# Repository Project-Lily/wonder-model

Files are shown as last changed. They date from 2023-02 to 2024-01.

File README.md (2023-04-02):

<div style="text-align: center">
<h1>Wonder Reader</h1>
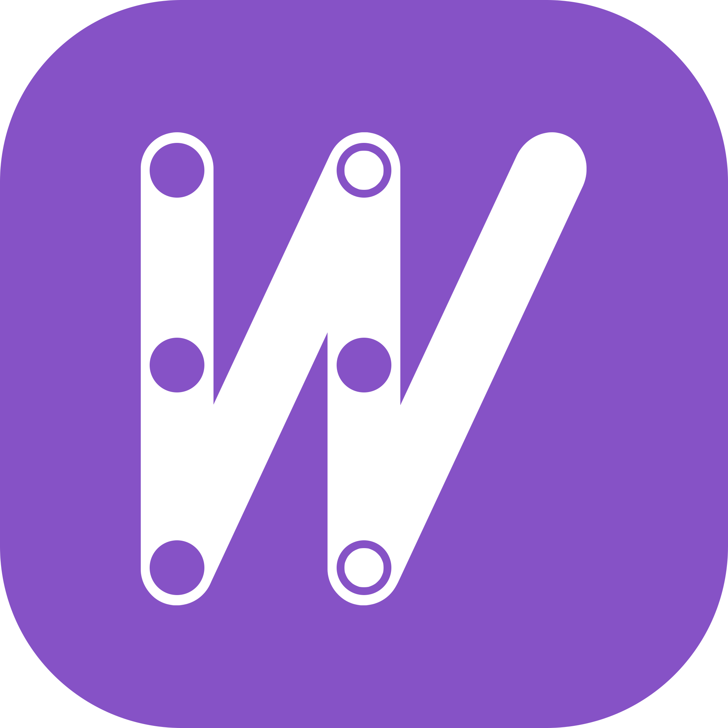
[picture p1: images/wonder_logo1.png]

<p>Repository for circuit, and 3D CAD models<p>
</div>

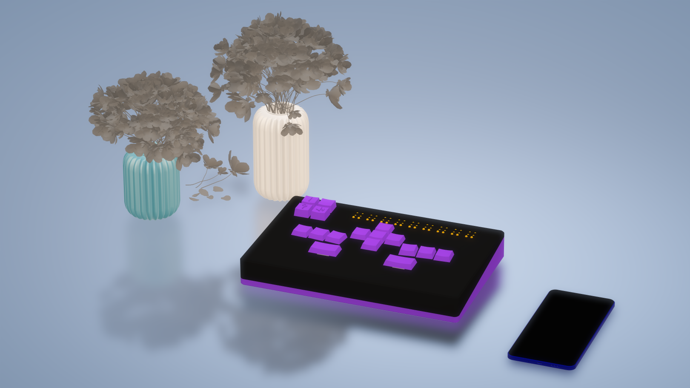
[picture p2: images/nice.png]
nice


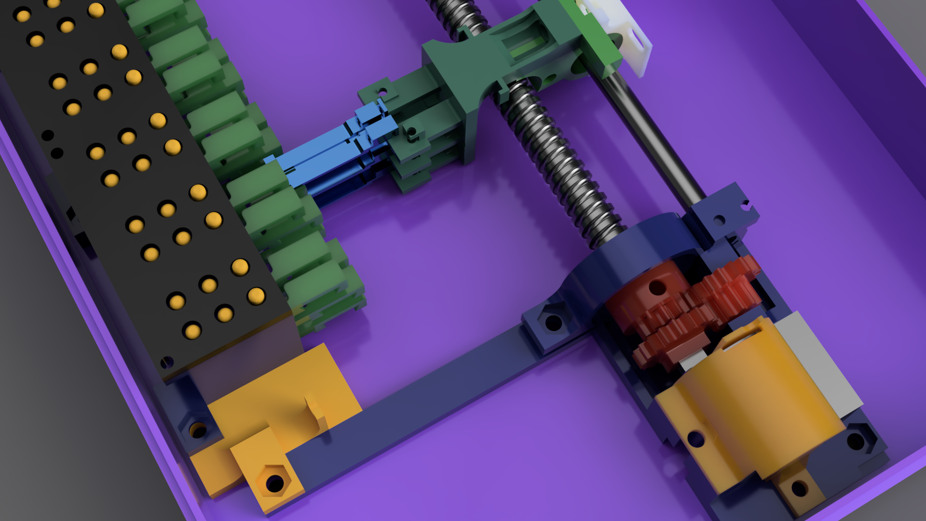
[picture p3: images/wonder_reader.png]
header


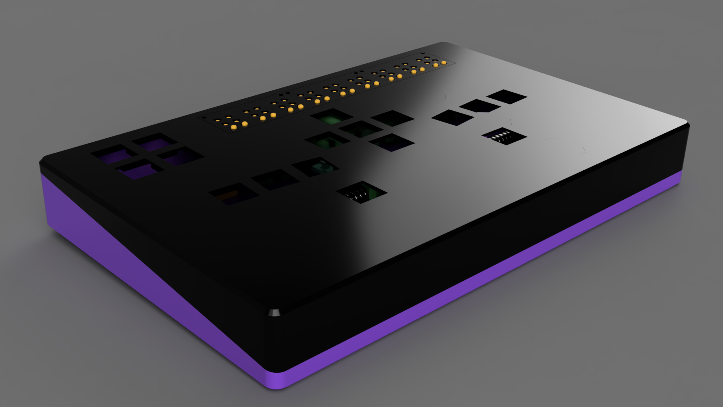
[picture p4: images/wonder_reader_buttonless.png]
buttonless


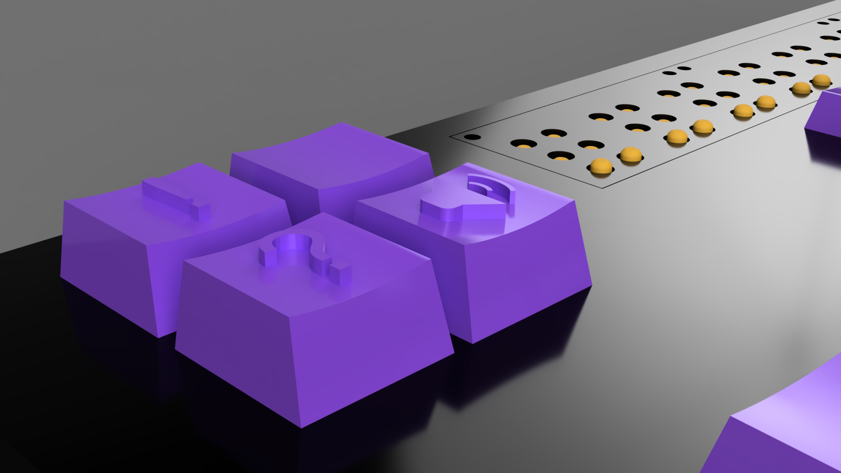
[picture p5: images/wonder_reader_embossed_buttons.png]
buttons


### Circuit
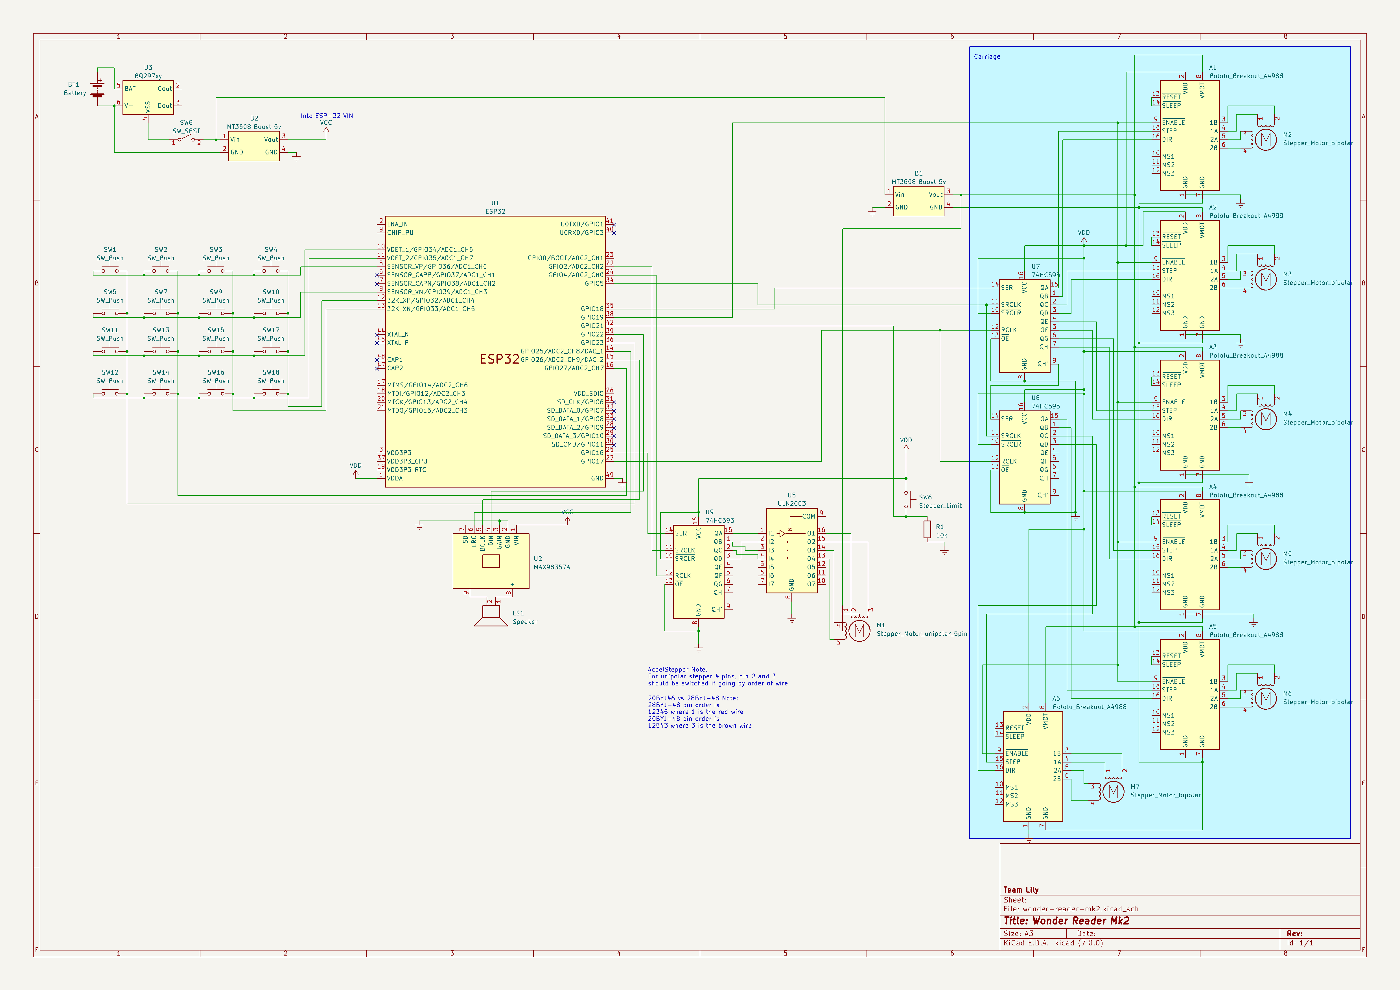
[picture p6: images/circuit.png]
circuit


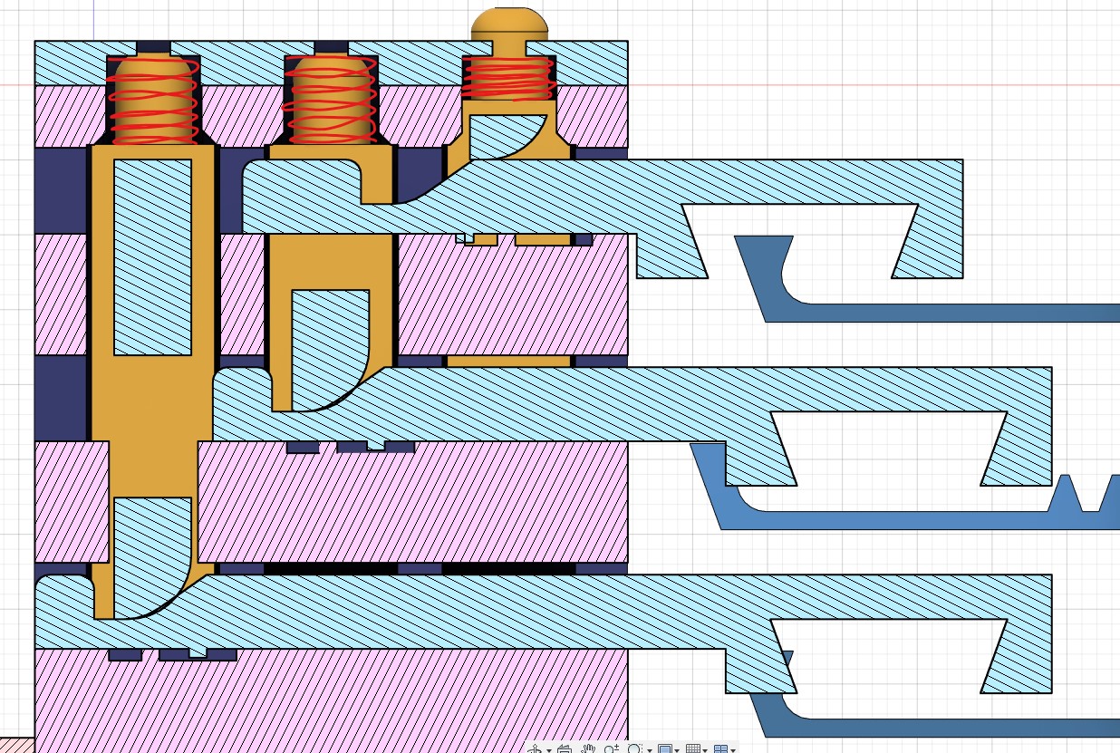
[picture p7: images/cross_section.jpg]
cross_section


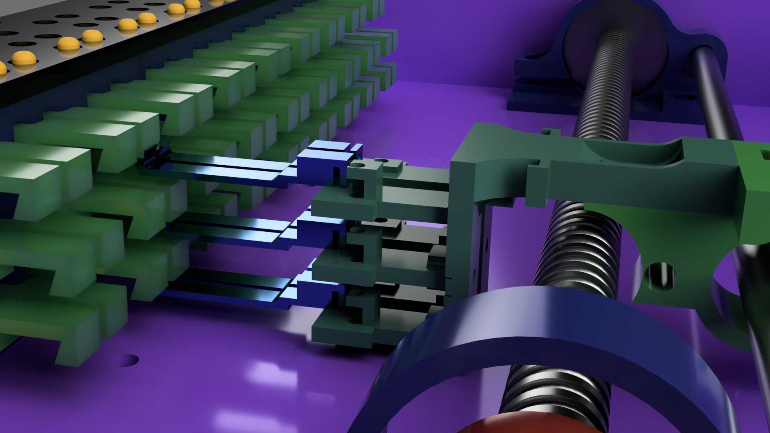
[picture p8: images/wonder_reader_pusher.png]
pusher


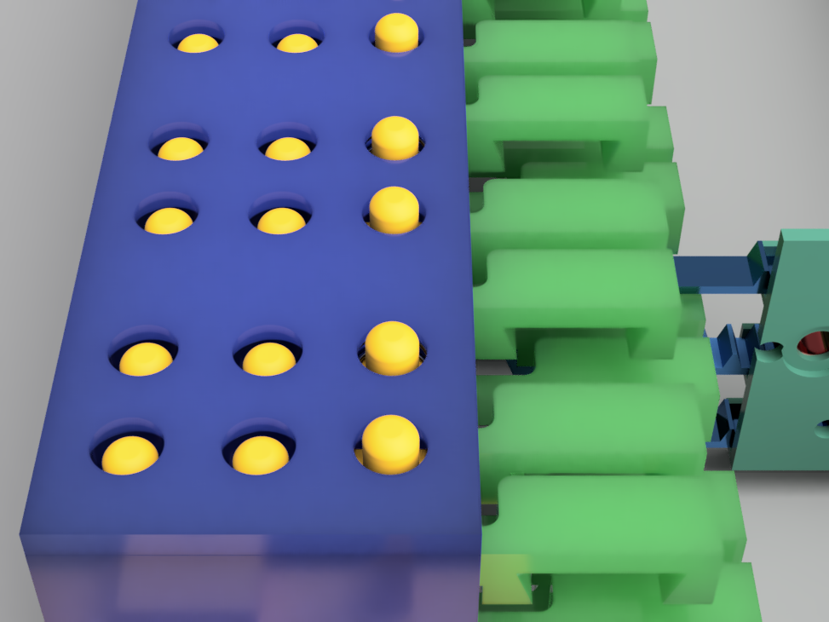
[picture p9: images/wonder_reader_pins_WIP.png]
pins


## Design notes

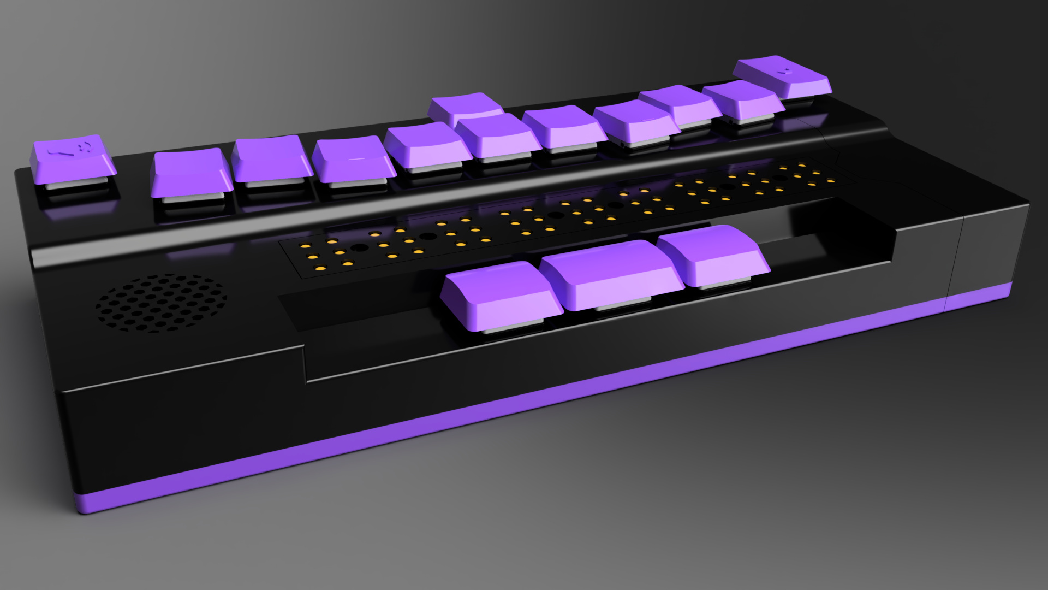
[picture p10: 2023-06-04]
images/v2.jpg

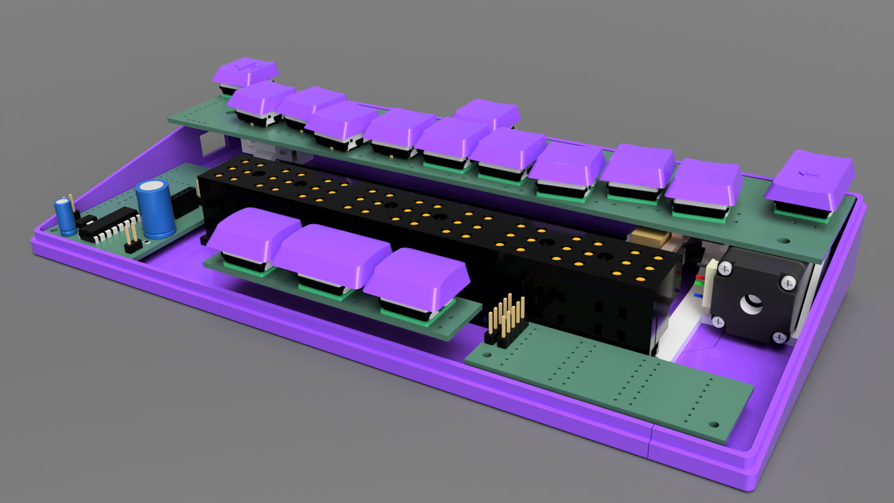
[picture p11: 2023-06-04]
images/v2xray.png

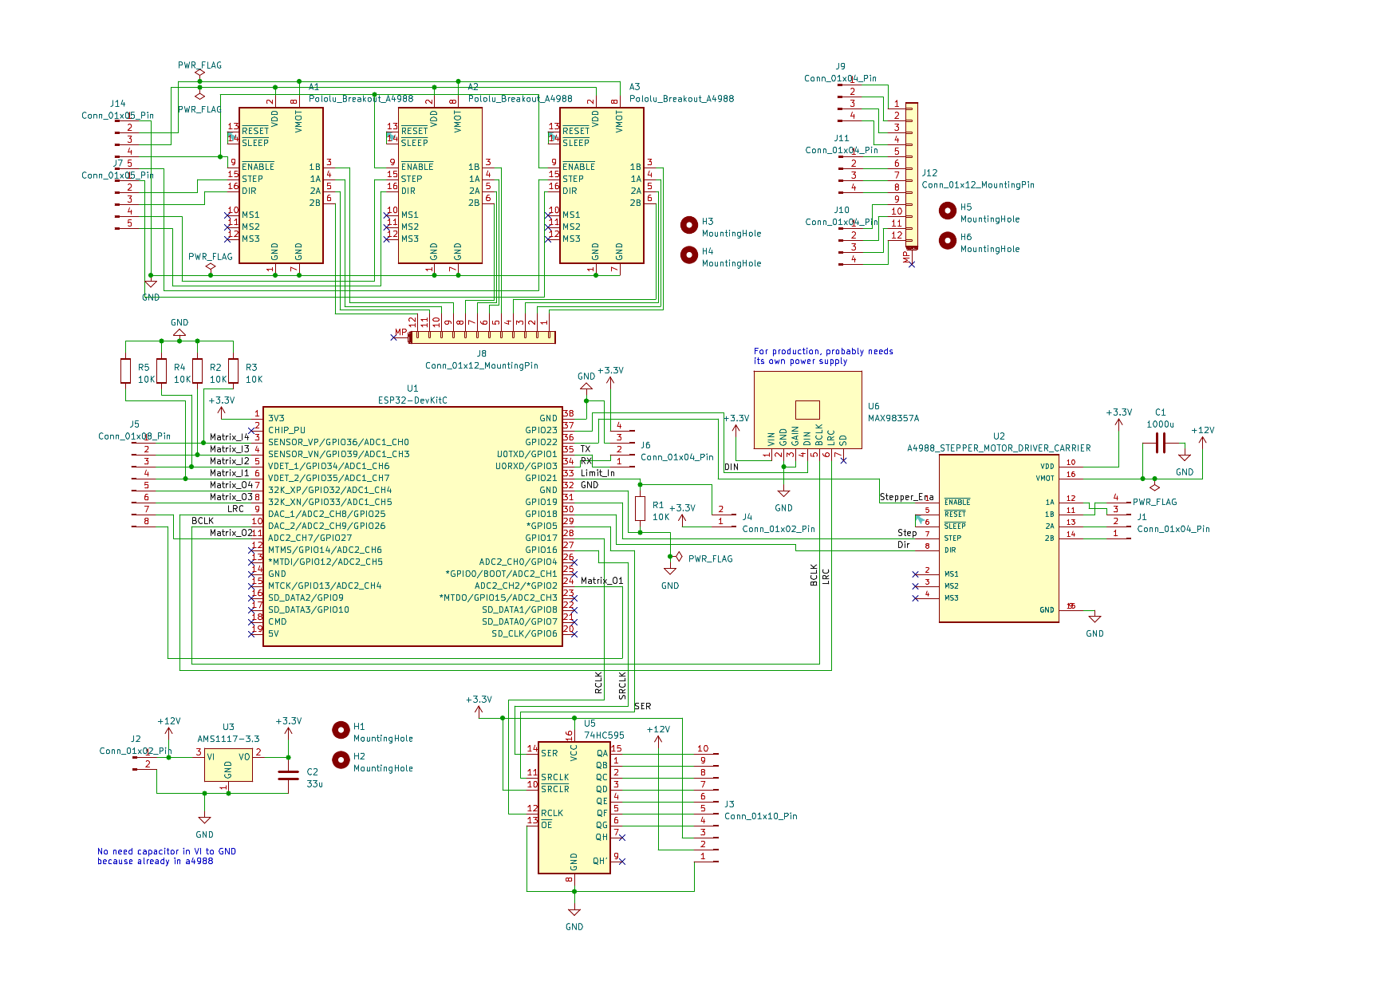
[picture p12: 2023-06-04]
images/v2circuit.png

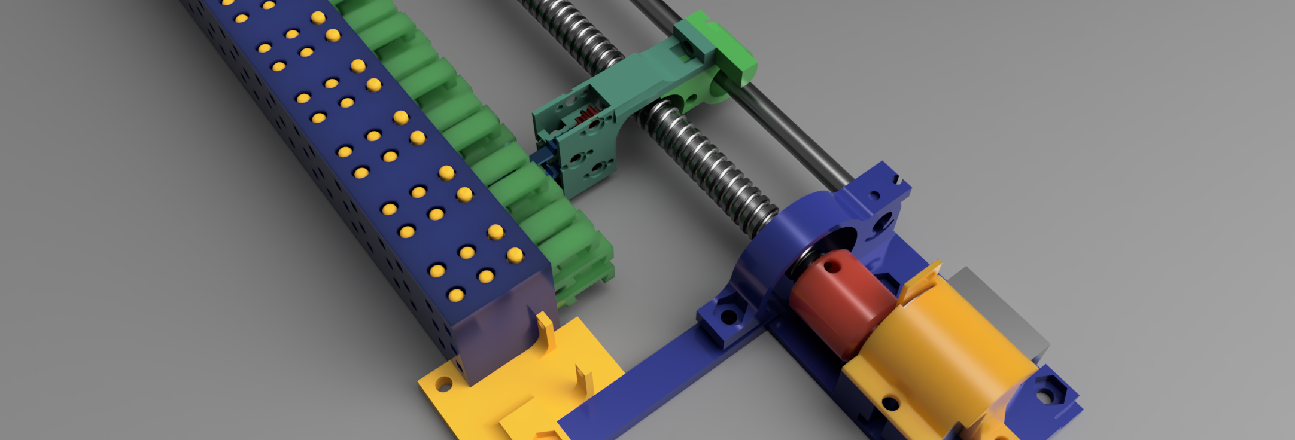
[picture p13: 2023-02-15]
images/wonder_reader_WIP.png

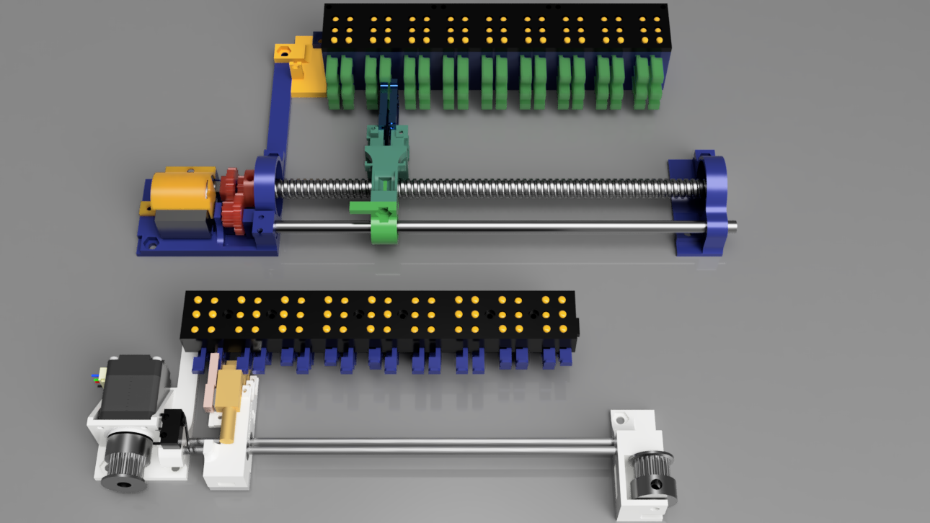
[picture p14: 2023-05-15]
images/v2comparison.png

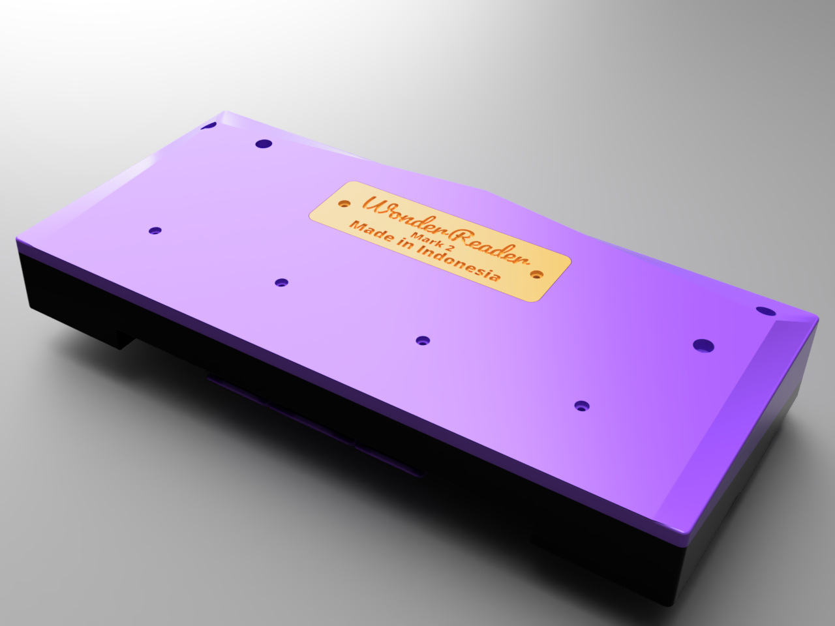
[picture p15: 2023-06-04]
images/v2back.jpg

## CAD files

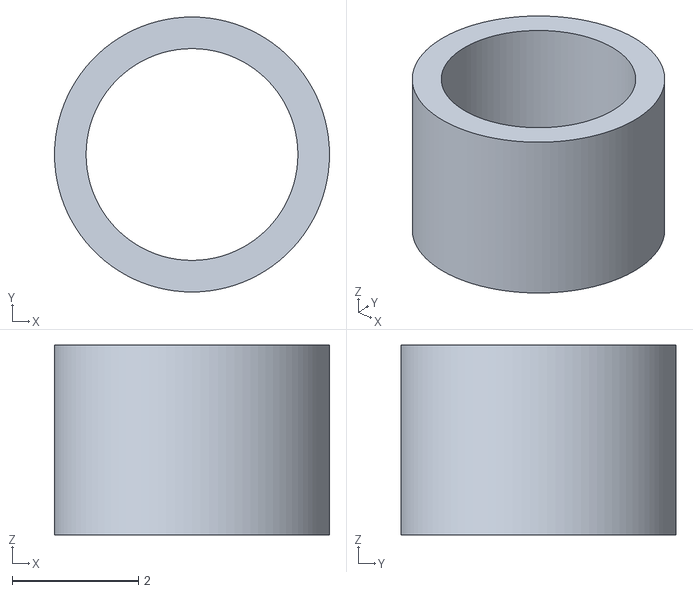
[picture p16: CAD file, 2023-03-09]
prototype/misc/spacer_m3_3.stl
4.35 x 4.35 x 3.00

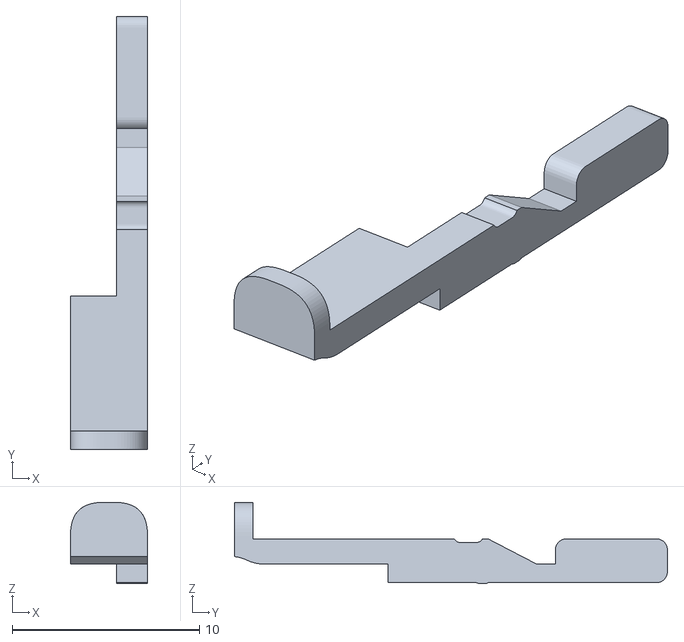
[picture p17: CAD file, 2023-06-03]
prototype/Mk2/wedge5.stl
4.12 x 23.1 x 4.35

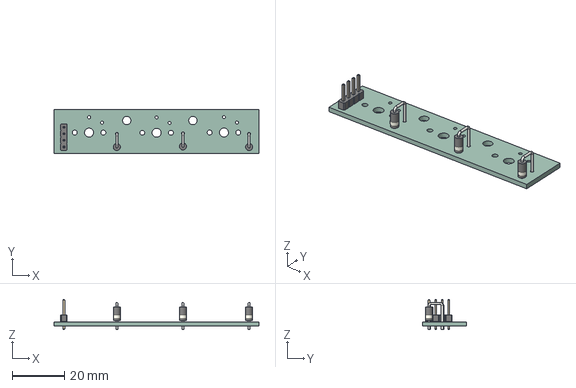
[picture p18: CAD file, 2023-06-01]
wonder-reader-mk2/bottom_keyboard_pcb/bottom_keyboard_pcb.step
78.7 x 17.0 x 11.5 mm
PCB

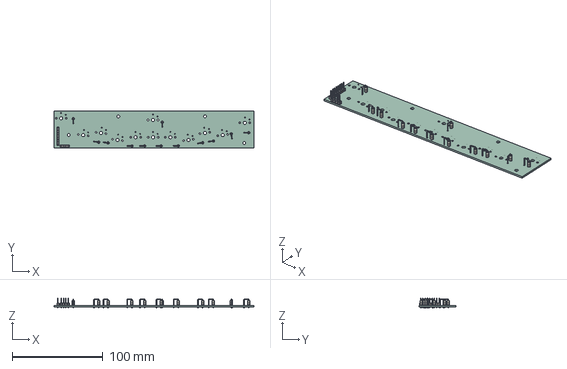
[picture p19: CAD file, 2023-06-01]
wonder-reader-mk2/top_keyboard_pcb/top_keyboard_pcb.step
220.0 x 41.0 x 11.5 mm
PCB

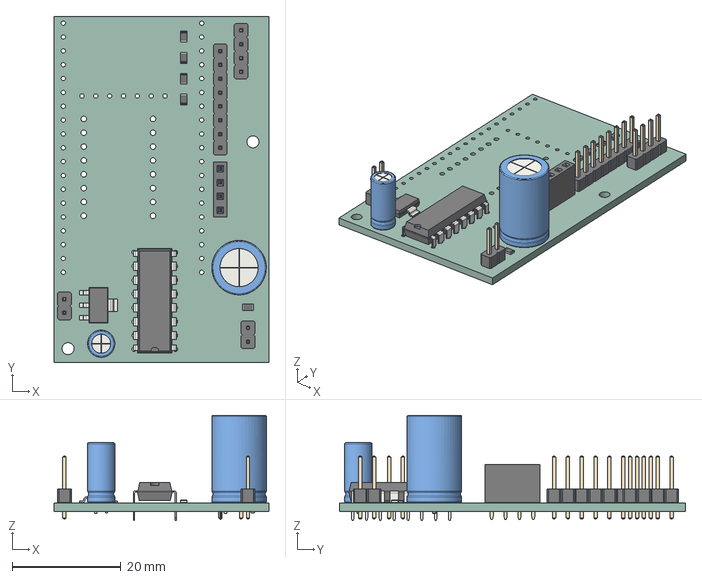
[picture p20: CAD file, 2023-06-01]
wonder-reader-mk2/wonder-reader-mk2-v2.step
39.4 x 63.5 x 19.3 mm
PCB

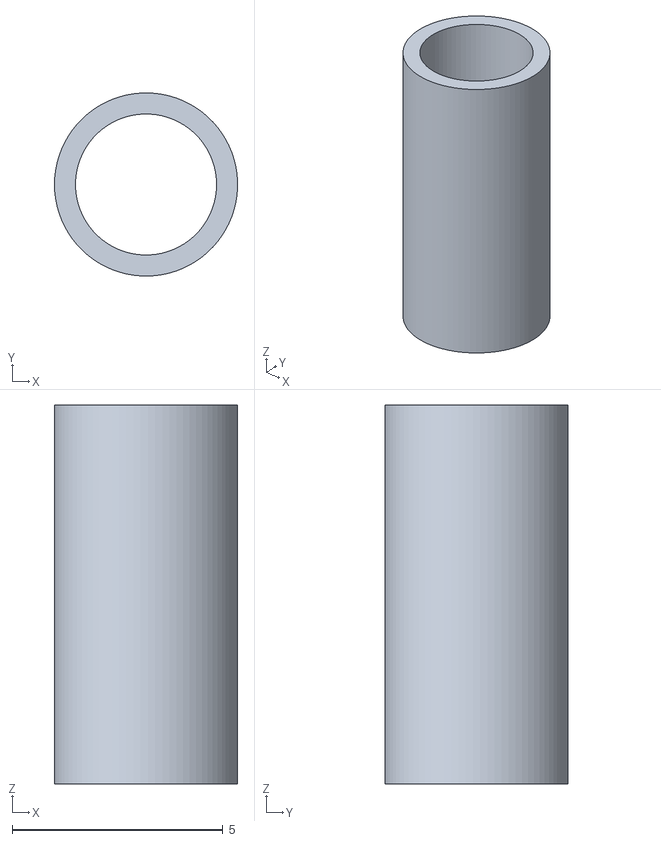
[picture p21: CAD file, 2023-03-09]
prototype/misc/spacer_m3_9.stl
4.35 x 4.35 x 9.00

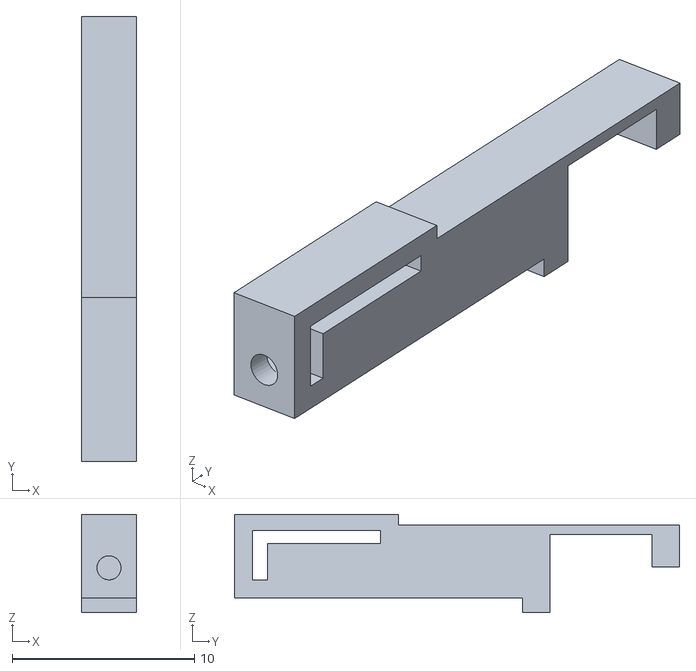
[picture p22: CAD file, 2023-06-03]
prototype/Mk2/arm_new.stl
3.00 x 24.4 x 5.40

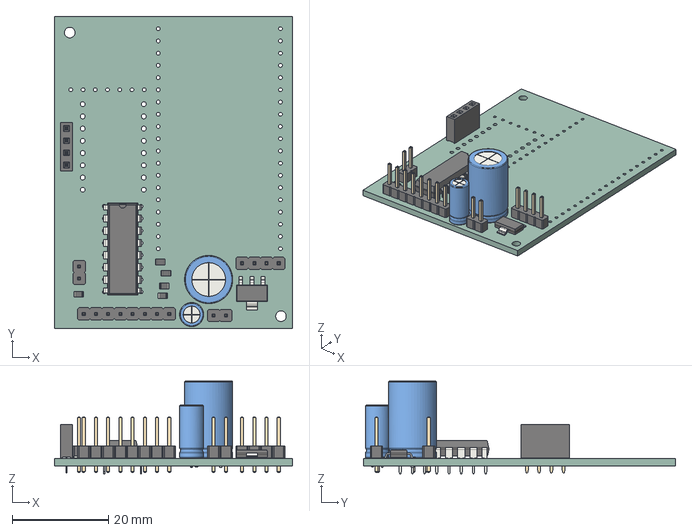
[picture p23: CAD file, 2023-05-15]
wonder-reader-mk2/wonder-reader-mk2.step
49.5 x 64.8 x 19.3 mm
PCB

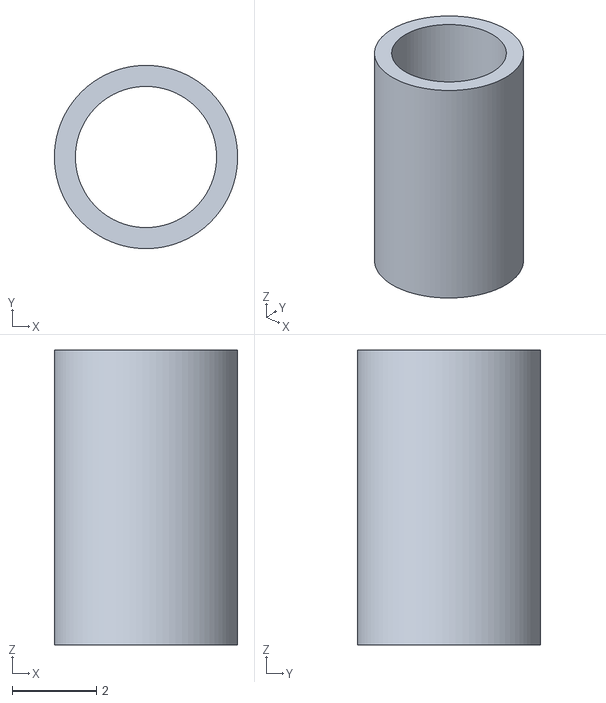
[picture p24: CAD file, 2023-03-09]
prototype/misc/spacer_m3_7.stl
4.35 x 4.35 x 7.00

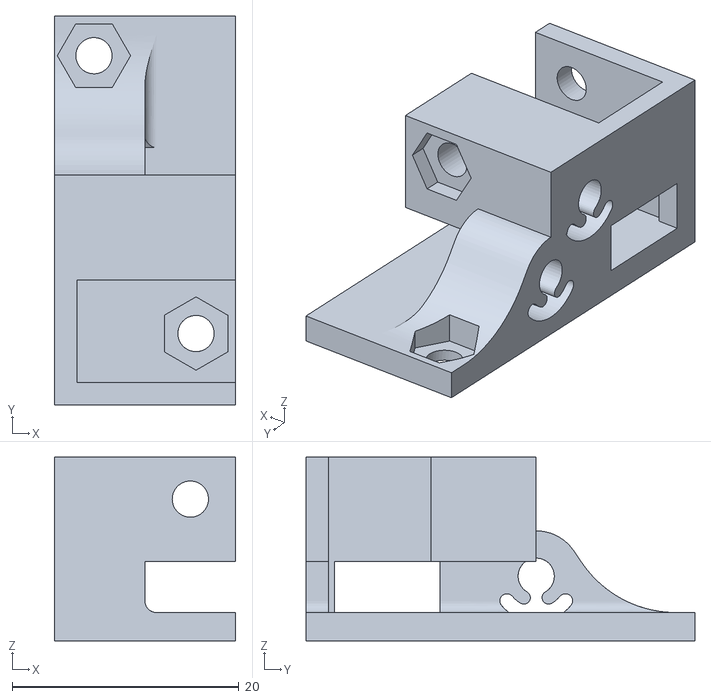
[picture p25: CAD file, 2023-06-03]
prototype/Mk2/holder-right.stl
16.0 x 34.3 x 16.2

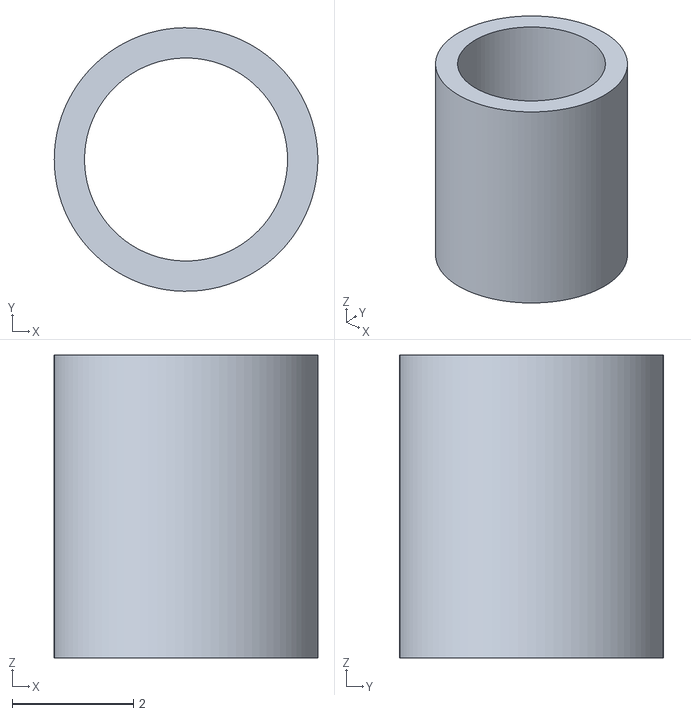
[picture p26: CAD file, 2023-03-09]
prototype/misc/spacer_m3_5.stl
4.35 x 4.35 x 5.00

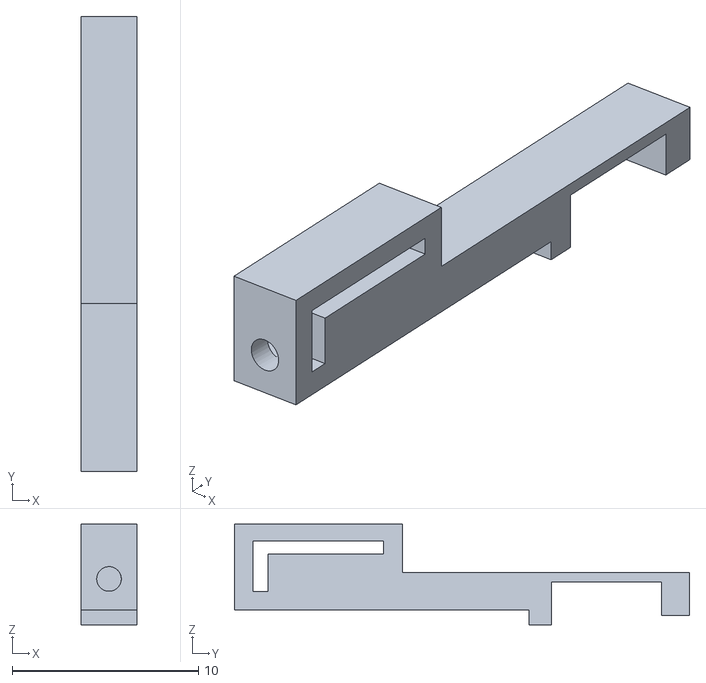
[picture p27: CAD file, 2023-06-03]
prototype/Mk2/arm.stl
3.00 x 24.4 x 5.40

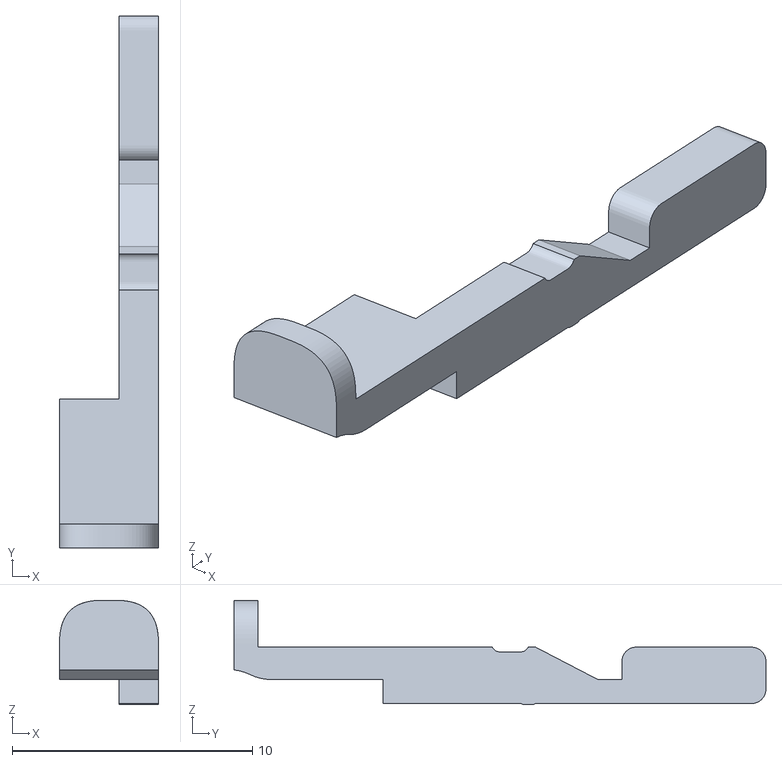
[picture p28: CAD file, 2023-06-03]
prototype/Mk2/wedge4.stl
4.12 x 22.1 x 4.35

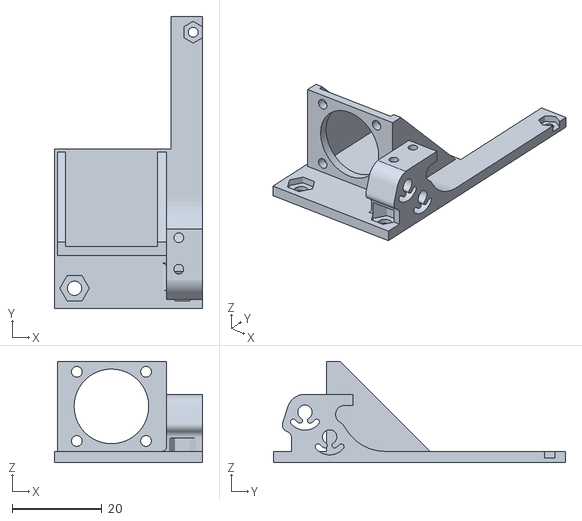
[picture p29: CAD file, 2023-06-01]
prototype/Mk2/left-holder.stl
33.0 x 65.0 x 22.5

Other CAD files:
prototype/Mk2/keycap1.25.stl
prototype/Mk2/keycapbump.stl
prototype/Mk2/top-2.stl
prototype/Mk2/holder-left.stl
old/prototype/Mk0/Wonder Reader Mk 0_1.stl
old/prototype/Mk0/Wonder Reader Mk 1 v68.stl
old/prototype/Mk1/Body40.stl
old/prototype/Mk1/Wonder Reader Mk2.3mf
old/prototype/Mk1/badge.stl
old/prototype/Mk1/bearing_bracket_end.stl
old/prototype/Mk1/bearing_bracket_start.stl
old/prototype/Mk1/carriage.stl
old/prototype/Mk1/case_bottom_L.stl
old/prototype/Mk1/case_bottom_R.stl
old/prototype/Mk1/case_top_L.stl
old/prototype/Mk1/case_top_R.stl
old/prototype/Mk1/cell_body.stl
old/prototype/Mk1/cell_body_3.stl
old/prototype/Mk1/cell_top.stl
old/prototype/Mk1/cell_top_3.stl
old/prototype/Mk1/gearbox_1.stl
old/prototype/Mk1/gearbox_2.stl
old/prototype/Mk1/gearbox_3_lead_adapter.stl
old/prototype/Mk1/grabber_mk1/carriage_load_L.stl
old/prototype/Mk1/grabber_mk1/carriage_load_R.stl
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

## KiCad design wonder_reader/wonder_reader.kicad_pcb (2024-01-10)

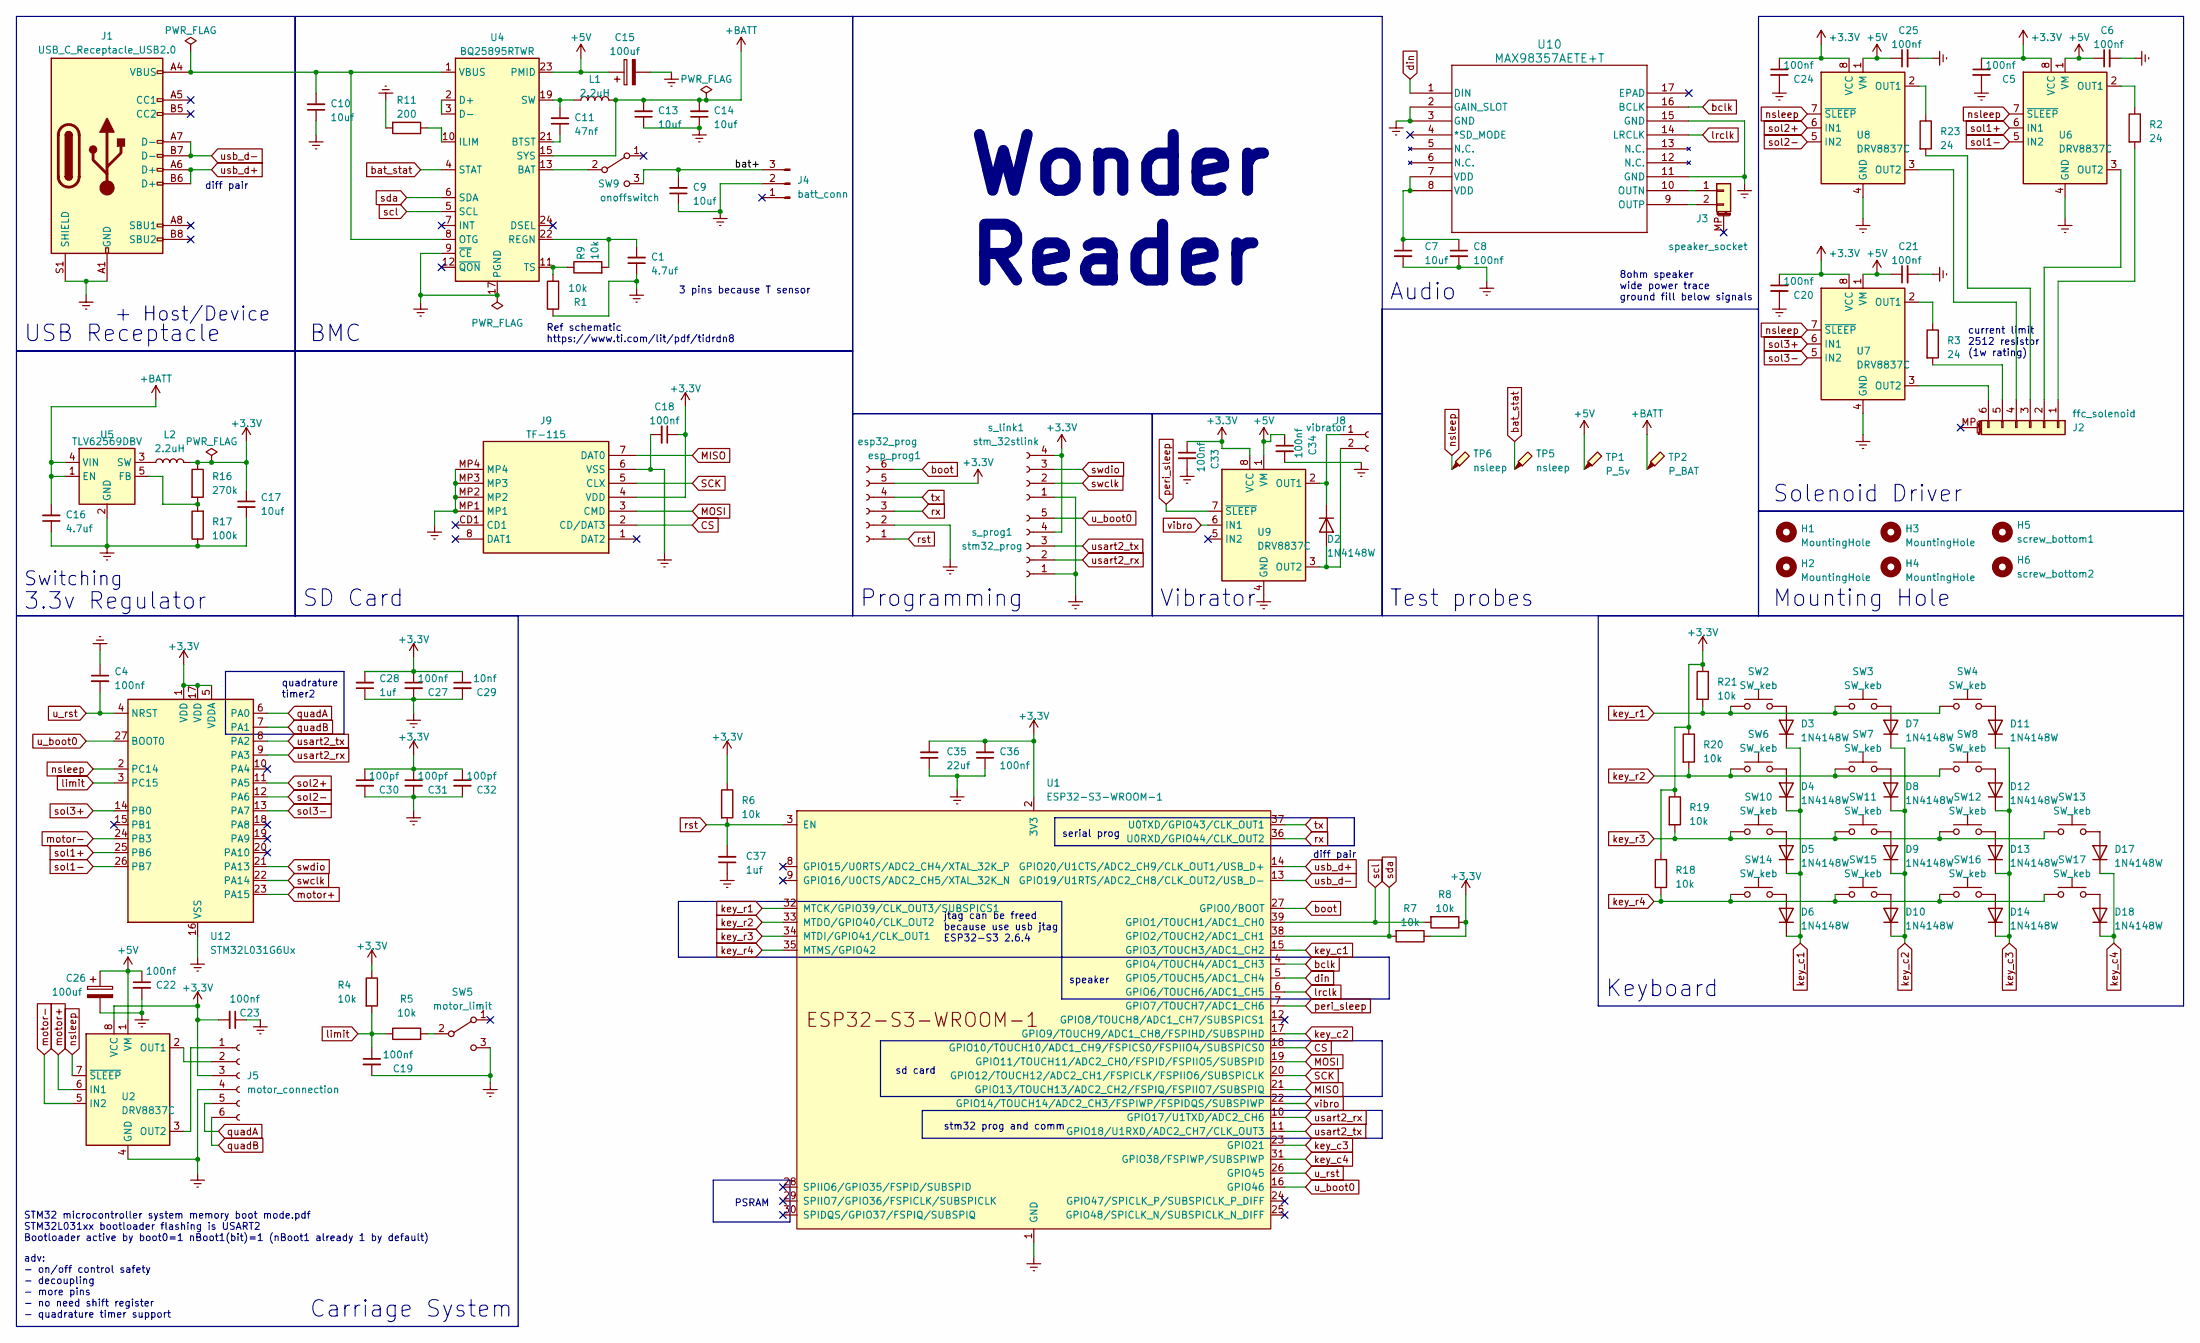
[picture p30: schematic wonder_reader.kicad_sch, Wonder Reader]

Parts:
C1, C16: 4.7uf; C_0805_2012Metric; LCSC Part C1779
C4, C5, C6, C8, C18, C19, C20, C21, C22, C23, C24, C25, C27, C33, C34, C36: 100nf; C_0402_1005Metric; LCSC Part C1525
C7, C9, C10, C13, C14, C17: 10uf; C_0805_2012Metric; LCSC Part C15850
C11: 47nf; C_0603_1608Metric; LCSC Part C1622
C15, C26: 100uf; CP_Elec_6.3x5.4; LCSC Part C1622
C28, C37: 1uf; C_0402_1005Metric; LCSC Part C52923
C29: 10nf; C_0402_1005Metric; LCSC Part C15195
C30, C31, C32: 100pf; C_0402_1005Metric; LCSC Part C1546
C35: 22uf; C_0805_2012Metric; LCSC Part C45783
D2, D3, D4, D5, D6, D7, D8, D9, D10, D11, D12, D13, D14, D17, D18: 1N4148W; D_SOD-123; LCSC Part C81598
H1, H2, H3, H4: MountingHole; MountingHole_2.2mm_M2
H5: screw_bottom1; MountingHole_5.3mm_M5
H6: screw_bottom2; MountingHole_5.3mm_M5
J1: USB_C_Receptacle_USB2.0; USB_C_Receptacle_G-Switch_GT-USB-7010ASV; LCSC Part C2765186
J2: ffc_solenoid; Hirose_FH12-6S-0.5SH_1x06-1MP_P0.50mm_Horizontal; LCSC Part C2856796
J3: speaker_socket; JST_GH_BM02B-GHS-TBT_1x02-1MP_P1.25mm_Vertical; LCSC Part C161690
J4: batt_conn; JST_PH_S3B-PH-K_1x03_P2.00mm_Horizontal; LCSC Part C157929
J5: motor_connection; PinHeader_1x06_P1.27mm_Vertical
J8: vibrator; PinHeader_1x02_P1.27mm_Vertical
J9: TF-115; TF115; Manufacturer_Part_Number TF-115; LCSC Part C266620
L1, L2: 2.2uH; L_1210_3225Metric; LCSC Part C295335
R1, R4, R5, R6, R7, R8, R9, R18, R19, R20, R21: 10k; R_0603_1608Metric; LCSC Part C25804
R2, R3, R23: 24; R_2512_6332Metric
R11: 200; R_0603_1608Metric; LCSC Part C8218
R16: 270k; R_0603_1608Metric; LCSC Part C103491
R17: 100k; R_0603_1608Metric; LCSC Part C25803
SW2, SW3, SW4, SW6, SW7, SW8, SW10, SW11, SW12, SW13, SW14, SW15, SW16, SW17: SW_keb; SW_Kailh_Choc_V1
SW5: motor_limit; SW_XKB_DM1-16UC-1; LCSC Part C466019
SW9: onoffswitch; G-Switch MK-12C02-G025; LCSC Part C963206
TP1: P_5v; TestPoint_Pad_1.0x1.0mm
TP2: P_BAT; TestPoint_Pad_1.0x1.0mm
TP5, TP6: nsleep; TestPoint_Pad_1.0x1.0mm
U1: ESP32-S3-WROOM-1; LCSC Part C2913197
U2, U6, U7, U8, U9: DRV8837C; WSON-8-1EP_2x2mm_P0.5mm_EP0.9x1.6mm; LCSC Part C191000
U4: BQ25895RTWR; Texas_S-PWQFN-N24_EP2.7x2.7mm_ThermalVias; LCSC Part C80200
U5: TLV62569DBV; SOT-23-5; LCSC Part C141836
U10: MAX98357AETE+T; 21-0136I_T1633-4_MXM; LCSC Part C910544
U12: STM32L031G6Ux; QFN-28_4x4mm_P0.5mm; LCSC Part C96514
esp_prog1: esp32_prog; PinHeader_1x06_P2.00mm_Vertical
s_link1: stm_32stlink; PinHeader_1x04_P2.00mm_Vertical
s_prog1: stm32_prog; PinHeader_1x05_P2.00mm_Vertical

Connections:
+3.3V: C5.1, C17.1, C18.1, C20.1, C23.2, C24.1, C27.1, C28.2, C29.1, C30.1, C31.1, C32.1, C33.1, C35.2, C36.2, J5.3, J9.4 (VDD), L2.2, R4.1, R6.1, R7.1, R8.1, R16.1, R18.1, R19.1, R20.1, R21.1, U1.2 (3V3), U2.8 (VCC), U6.8 (VCC), U7.8 (VCC), U8.8 (VCC), U9.8 (VCC), U12.1 (VDD), U12.5 (VDDA), U12.17 (VDD), esp_prog1.5, s_link1.4, s_prog1.4
+5V: C6.1, C15.1, C21.1, C22.1, C25.1, C26.1, C34.1, TP1.1, U2.1 (VM), U4.23 (PMID), U6.1 (VM), U7.1 (VM), U8.1 (VM), U9.1 (VM)
+BATT: C13.2, C14.2, C16.2, L1.2, TP2.1, U4.15 (SYS), U4.16 (SYS), U5.1 (EN), U5.4 (VIN)
/bat+: C9.2, J4.3, SW9.3 (C)
CS: J9.2 (CD/DAT3), U1.18 (GPIO10/TOUCH10/ADC1_CH9/FSPICS0/FSPIIO4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)
Earth: C1.1, C4.1, C5.2, C6.2, C7.2, C8.2, C9.1, C10.1, C13.1, C14.1, C15.2, C16.1, C17.2, C18.2, C19.2, C20.2, C21.2, C22.2, C23.1, C24.2, C25.2, C26.2, C27.2, C28.1, C29.2, C30.2, C31.2, C32.2, C33.2, C34.2, C35.1, C36.1, C37.1, J1.A1 (GND), J1.A12 (GND), J1.B1 (GND), J1.B12 (GND), J1.S1 (SHIELD), J4.2, J5.4, J9.6 (VSS), J9.MP1, J9.MP2, J9.MP3, J9.MP4, R1.1, R11.2, R17.1, SW5.3 (C), U1.1 (GND), U1.40 (GND), U1.41 (GND), U2.4 (GND), U2.9 (GND), U4.9 (~CE), U4.17 (PGND), U4.18 (PGND), U4.25 (PGND), U5.2 (GND), U6.4 (GND), U6.9 (GND), U7.4 (GND), U7.9 (GND), U8.4 (GND), U8.9 (GND), U9.4 (GND), U9.9 (GND), U10.2 (GAIN_SLOT), U10.3 (GND), U10.11 (GND), U10.15 (GND), U12.16 (VSS), U12.28 (VSS), esp_prog1.2, s_link1.1, s_prog1.1
MISO: J9.7 (DAT0), U1.21 (GPIO13/TOUCH13/ADC2_CH2/FSPIQ/FSPIIO7/S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)
MOSI: J9.3 (CMD), U1.19 (GPIO11/TOUCH11/ADC2_CH0/FSPID/FSPIIO5/S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)
unnamed: C7.1, C8.1, U10.7 (VDD), U10.8 (VDD)
unnamed: C11.2, L1.1, U4.19 (SW), U4.20 (SW)
unnamed: D2.2 (A), J8.2, U9.3 (OUT2)
unnamed: D2.1 (K), J8.1, U9.2 (OUT1)
unnamed: D3.2 (A), SW2.2
unnamed: D4.2 (A), SW6.2
unnamed: D5.2 (A), SW10.2
unnamed: D6.2 (A), SW14.2
unnamed: D7.2 (A), SW3.2
unnamed: D8.2 (A), SW7.2
unnamed: D9.2 (A), SW11.2
unnamed: D10.2 (A), SW15.2
unnamed: D11.2 (A), SW4.2
unnamed: D12.2 (A), SW8.2
unnamed: D13.2 (A), SW12.2
unnamed: D14.2 (A), SW16.2
unnamed: D17.2 (A), SW13.2
unnamed: D18.2 (A), SW17.2
unnamed: J2.1, R2.2
unnamed: J2.2, U6.3 (OUT2)
unnamed: J2.3, R23.2
unnamed: J2.4, U8.3 (OUT2)
unnamed: J2.5, R3.2
unnamed: J2.6, U7.3 (OUT2)
unnamed: J3.1, U10.10 (OUTN)
unnamed: J3.2, U10.9 (OUTP)
unnamed: J5.1, U2.3 (OUT2)
unnamed: J5.2, U2.2 (OUT1)
unnamed: R5.2, SW5.2 (B)
unnamed: SW9.2 (B), U4.13 (BAT), U4.14 (BAT)
unnamed: C11.1, U4.21 (BTST)
unnamed: U4.2 (D+), U4.3 (D-)
unnamed: R11.1, U4.10 (ILIM)
unnamed: C10.2, J1.A4 (VBUS), J1.A9 (VBUS), J1.B4 (VBUS), J1.B9 (VBUS), U4.1 (VBUS), U4.8 (OTG)
unnamed: C1.2, R9.2, U4.22 (REGN)
unnamed: R1.2, R9.1, U4.11 (TS)
unnamed: R16.2, R17.2, U5.5 (FB)
unnamed: L2.1, U5.3 (SW)
unnamed: R2.1, U6.2 (OUT1)
unnamed: R3.1, U7.2 (OUT1)
unnamed: R23.1, U8.2 (OUT1)
SCK: J9.5 (CLX), U1.20 (GPIO12/TOUCH12/ADC2_CH1/FSPICLK/FSPIIO6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)
bat_stat: TP5.1, U4.4 (STAT)
bclk: U1.4 (GPIO4/TOUCH4/ADC1_CH3), U10.16 (BCLK)
boot: U1.27 (GPIO0/BOOT), esp_prog1.6
din: U1.5 (GPIO5/TOUCH5/ADC1_CH4), U10.1 (DIN)
key_c1: D3.1 (K), D4.1 (K), D5.1 (K), D6.1 (K), U1.15 (GPIO3/TOUCH3/ADC1_CH2)
key_c2: D7.1 (K), D8.1 (K), D9.1 (K), D10.1 (K), U1.17 (GPIO9/TOUCH9/ADC1_CH8/FSPIHD/SUBSPIHD)
key_c3: D11.1 (K), D12.1 (K), D13.1 (K), D14.1 (K), U1.23 (GPIO21)
key_c4: D17.1 (K), D18.1 (K), U1.31 (GPIO38/FSPIWP/SUBSPIWP)
key_r1: R21.2, SW2.1, SW3.1, SW4.1, U1.32 (MTCK/GPIO39/CLK_OUT3/SUBSPICS1)
key_r2: R20.2, SW6.1, SW7.1, SW8.1, U1.33 (MTDO/GPIO40/CLK_OUT2)
key_r3: R19.2, SW10.1, SW11.1, SW12.1, SW13.1, U1.34 (MTDI/GPIO41/CLK_OUT1)
key_r4: R18.2, SW14.1, SW15.1, SW16.1, SW17.1, U1.35 (MTMS/GPIO42)
limit: C19.1, R4.2, R5.1, U12.3 (PC15)
lrclk: U1.6 (GPIO6/TOUCH6/ADC1_CH5), U10.14 (LRCLK)
motor+: U2.6 (IN1), U12.23 (PA15)
motor-: U2.5 (IN2), U12.24 (PB3)
nsleep: TP6.1, U2.7 (~SLEEP), U6.7 (~SLEEP), U7.7 (~SLEEP), U8.7 (~SLEEP), U12.2 (PC14)
peri_sleep: U1.7 (GPIO7/TOUCH7/ADC1_CH6), U9.7 (~SLEEP)
quadA: J5.5, U12.6 (PA0)
quadB: J5.6, U12.7 (PA1)
rst: C37.2, R6.2, U1.3 (EN), esp_prog1.1
rx: U1.36 (U0RXD/GPIO44/CLK_OUT2), esp_prog1.3
scl: R8.2, U1.39 (GPIO1/TOUCH1/ADC1_CH0), U4.5 (SCL)
sda: R7.2, U1.38 (GPIO2/TOUCH2/ADC1_CH1), U4.6 (SDA)
sol1+: U6.6 (IN1), U12.25 (PB6)
sol1-: U6.5 (IN2), U12.26 (PB7)
sol2+: U8.6 (IN1), U12.11 (PA5)
sol2-: U8.5 (IN2), U12.12 (PA6)
sol3+: U7.6 (IN1), U12.14 (PB0)
sol3-: U7.5 (IN2), U12.13 (PA7)
swclk: U12.22 (PA14), s_link1.2
swdio: U12.21 (PA13), s_link1.3
tx: U1.37 (U0TXD/GPIO43/CLK_OUT1), esp_prog1.4
u_boot0: U1.16 (GPIO46), U12.27 (BOOT0), s_prog1.5
u_rst: C4.2, U1.26 (GPIO45), U12.4 (NRST)
usart2_rx: U1.10 (GPIO17/U1TXD/ADC2_CH6), U12.9 (PA3), s_prog1.2
usart2_tx: U1.11 (GPIO18/U1RXD/ADC2_CH7/CLK_OUT3), U12.8 (PA2), s_prog1.3
usb_d+: J1.A6 (D+), J1.B6 (D+), U1.14 (GPIO20/U1CTS/ADC2_CH9/CLK_OUT1/USB_D+)
usb_d-: J1.A7 (D-), J1.B7 (D-), U1.13 (GPIO19/U1RTS/ADC2_CH8/CLK_OUT2/USB_D-)
vibro: U1.22 (GPIO14/TOUCH14/ADC2_CH3/FSPIWP/FSPIDQS/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), U9.6 (IN1)

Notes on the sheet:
BMC
3 pins because T sensor
8ohm speaker wide power trace ground fill below signals
Wonder Reader
STM32 microcontroller system memory boot mode.pdf STM32L031xx bootloader flashing is USART2 Bootloader active by boot0=1 nBoot1(bit)=1 (nBoot1 already 1 by default)
Mounting Hole
USB Receptacle
sd card
Ref schematic https://www.ti.com/lit/pdf/tidrdn8
Solenoid Driver
diff pair
+ Host/Device
quadrature timer2
3.3v Regulator
stm32 prog and comm
Vibrator
Keyboard
speaker
current limit 2512 resistor (1w rating)
jtag can be freed because use usb jtag ESP32-S3 2.6.4
Programming
Test probes
SD Card
Audio
serial prog
adv: - on/off control safety - decoupling - more pins - no need shift register - quadrature timer support
Switching
Carriage System
PSRAM

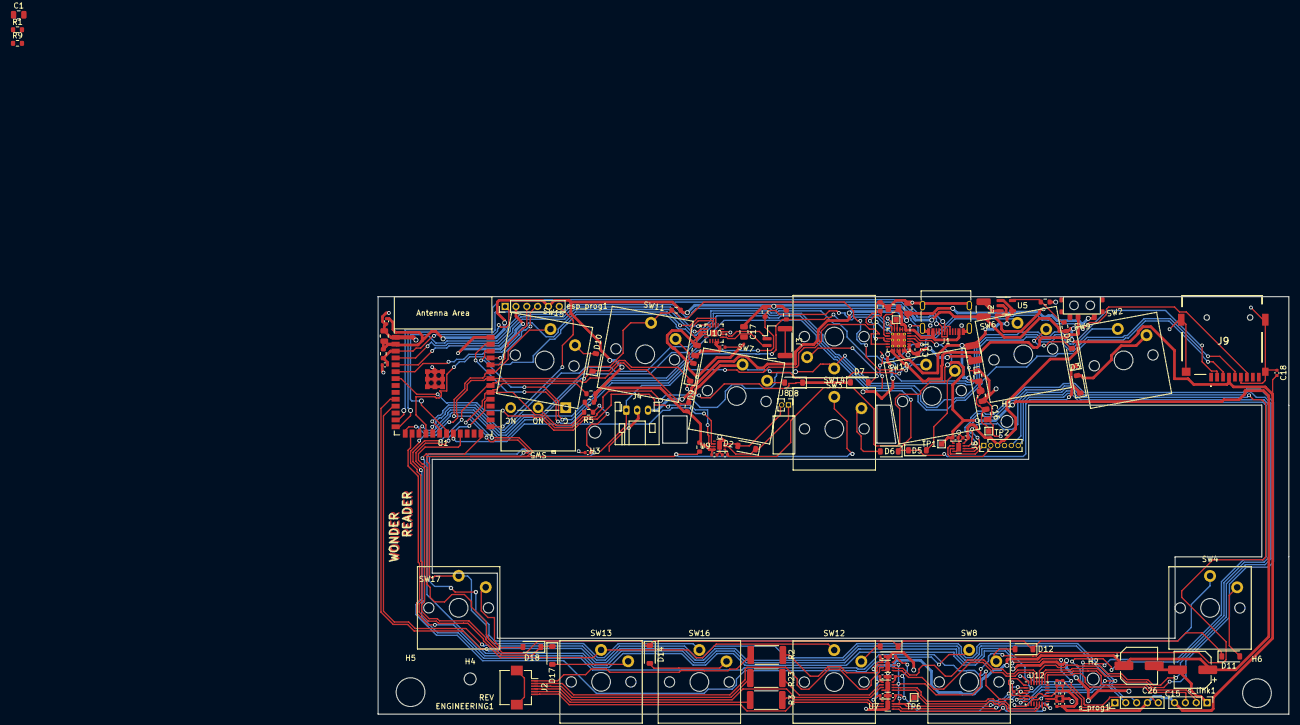
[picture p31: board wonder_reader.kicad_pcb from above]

Board: 2 copper layers, 168.0 x 77.0 mm, 114 parts (0 on the bottom side), 90 nets.

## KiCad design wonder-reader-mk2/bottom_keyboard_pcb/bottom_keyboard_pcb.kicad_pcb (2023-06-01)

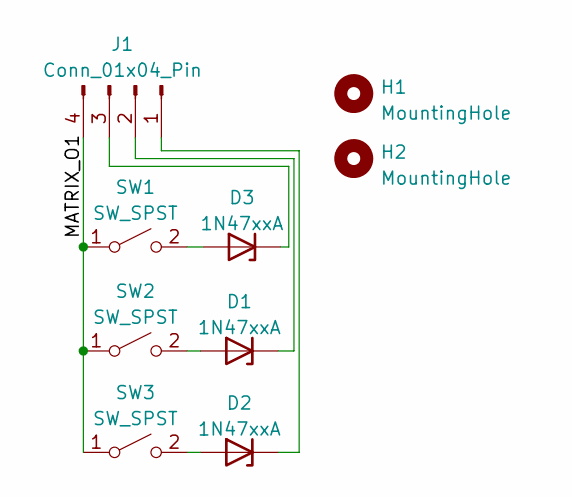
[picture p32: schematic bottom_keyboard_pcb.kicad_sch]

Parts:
D1, D2, D3: 1N47xxA; D_DO-41_SOD81_P5.08mm_Vertical_AnodeUp
H1, H2: MountingHole; MountingHole_3.2mm_M3
J1: Conn_01x04_Pin; PinHeader_1x04_P2.54mm_Vertical
SW1, SW2, SW3: SW_SPST; SW_Kailh_Choc_V1

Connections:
/MATRIX_O1: J1.4, SW1.1 (A), SW2.1 (A), SW3.1 (A)
unnamed: D1.2 (A), SW2.2 (B)
unnamed: D1.1 (K), J1.2
unnamed: D2.2 (A), SW3.2 (B)
unnamed: D2.1 (K), J1.1
unnamed: D3.2 (A), SW1.2 (B)
unnamed: D3.1 (K), J1.3

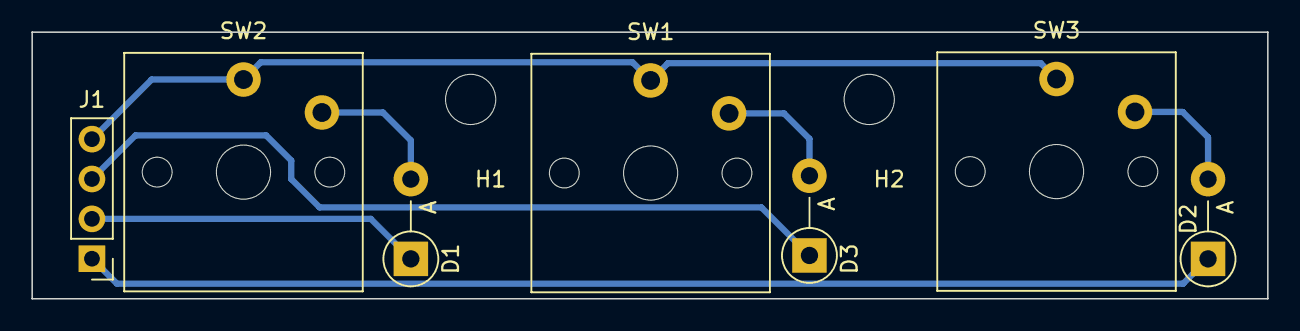
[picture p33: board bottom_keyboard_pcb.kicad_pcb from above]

Board: 2 copper layers, 78.7 x 17.0 mm, 9 parts (0 on the bottom side), 7 nets.

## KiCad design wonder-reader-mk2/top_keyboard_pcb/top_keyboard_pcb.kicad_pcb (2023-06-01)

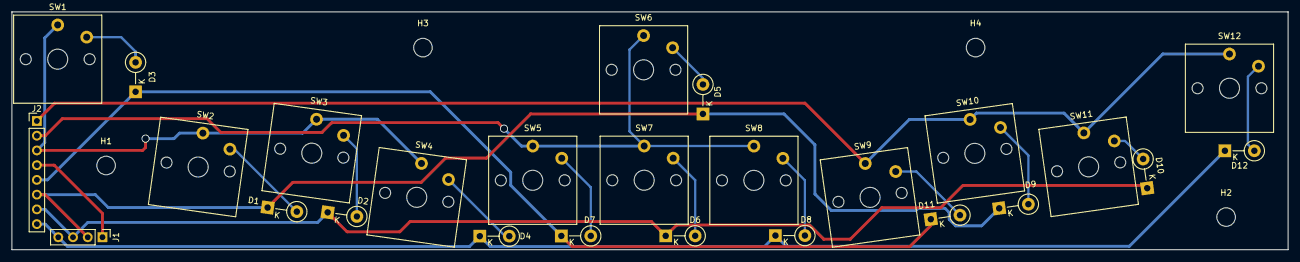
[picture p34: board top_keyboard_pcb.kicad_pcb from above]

Board: 2 copper layers, 220.0 x 41.0 mm, 30 parts (0 on the bottom side), 20 nets.

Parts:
D1, D2, D3, D4, D5, D6, D7, D8, D9, D10, D11, D12: 1N47xxA; D_DO-41_SOD81_P5.08mm_Vertical_KathodeUp
H1, H2, H3, H4: MountingHole; MountingHole_3.2mm_M3
J1: Conn_01x04_Pin; PinHeader_1x04_P2.54mm_Vertical
J2: Conn_01x08_Pin; PinHeader_1x08_P2.54mm_Vertical
SW1, SW2, SW3, SW4, SW5, SW6, SW7, SW8, SW9, SW10, SW11, SW12: SW_SPST; SW_Kailh_Choc_V1

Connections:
unnamed: D1.2 (A), SW2.2 (B)
unnamed: D1.1 (K), D5.1 (K), D9.1 (K), J1.2, J2.6
unnamed: D2.2 (A), SW3.2 (B)
unnamed: D3.2 (A), SW1.2 (B)
unnamed: D4.2 (A), SW4.2 (B)
unnamed: D5.2 (A), SW6.2 (B)
unnamed: D6.2 (A), SW7.2 (B)
unnamed: D7.2 (A), SW5.2 (B)
unnamed: D8.2 (A), SW8.2 (B)
unnamed: D9.2 (A), SW10.2 (B)
unnamed: D10.2 (A), SW11.2 (B)
unnamed: D2.1 (K), D6.1 (K), D10.1 (K), J1.3, J2.7
unnamed: D11.2 (A), SW9.2 (B)
unnamed: D3.1 (K), D7.1 (K), D11.1 (K), J2.5
unnamed: D12.2 (A), SW12.2 (B)
unnamed: D4.1 (K), D8.1 (K), D12.1 (K), J1.4, J2.8
unnamed: J1.1, J2.4
unnamed: J2.1, SW9.1 (A), SW10.1 (A), SW11.1 (A), SW12.1 (A)
unnamed: J2.2, SW5.1 (A), SW6.1 (A), SW7.1 (A), SW8.1 (A)
unnamed: J2.3, SW1.1 (A), SW2.1 (A), SW3.1 (A), SW4.1 (A)

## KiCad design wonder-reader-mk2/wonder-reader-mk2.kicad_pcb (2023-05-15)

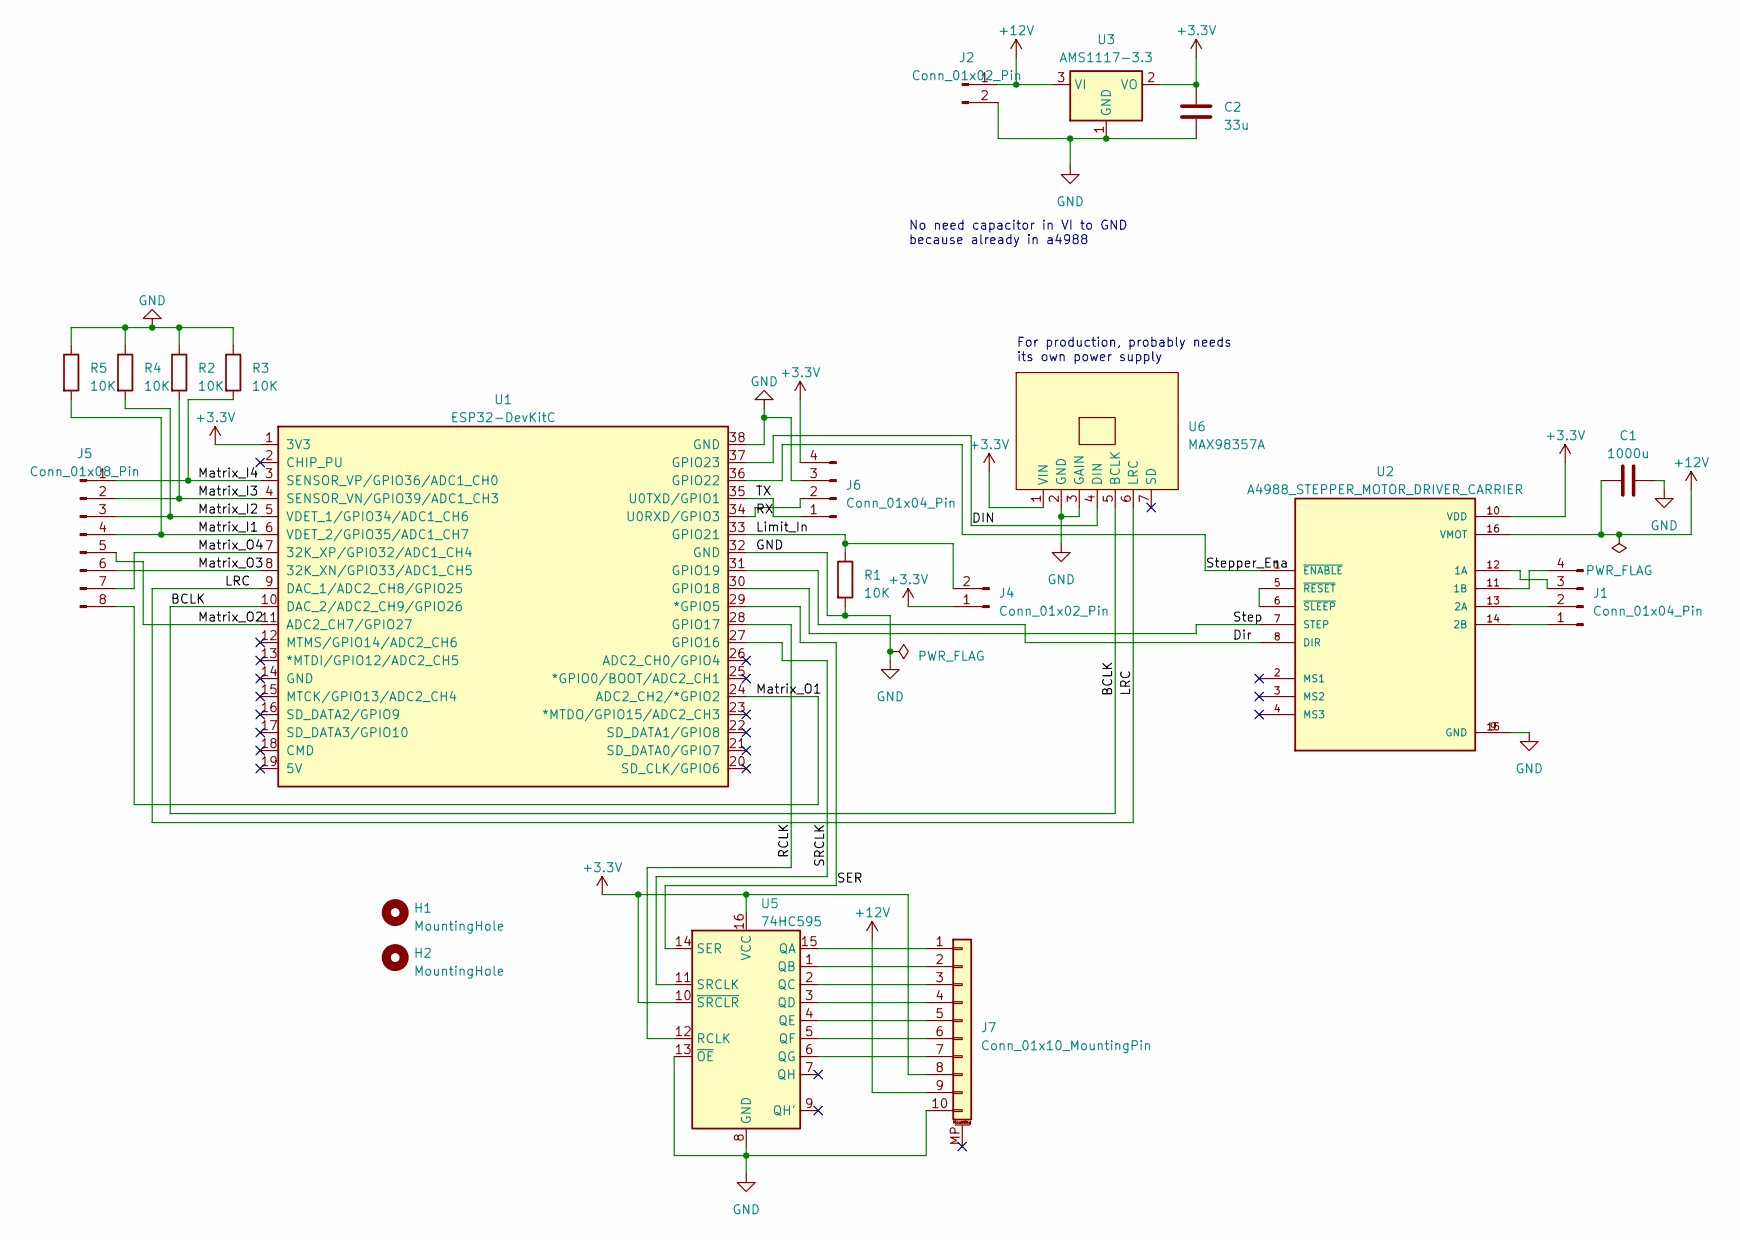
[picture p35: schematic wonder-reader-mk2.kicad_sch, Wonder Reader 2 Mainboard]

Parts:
C1: 1000u; C_Radial_D10.0mm_H16.0mm_P5.00mm
C2: 33u; C_Radial_D5.0mm_H11.0mm_P2.00mm
H1, H2: MountingHole; MountingHole_2.2mm_M2
J1: Conn_01x04_Pin; PinSocket_1x04_P2.54mm_Vertical
J2, J4: Conn_01x02_Pin; PinHeader_1x02_P2.54mm_Vertical
J5: Conn_01x08_Pin; PinHeader_1x08_P2.54mm_Vertical
J6: Conn_01x04_Pin; PinHeader_1x04_P2.54mm_Vertical
J7: Conn_01x10_MountingPin; Hirose_FH12-10S-0.5SH_1x10-1MP_P0.50mm_Horizontal
R1, R2, R3, R4, R5: 10K; R_0805_2012Metric
U1: ESP32-DevKitC
U2: A4988_STEPPER_MOTOR_DRIVER_CARRIER; MODULE_A4988_STEPPER_MOTOR_DRIVER_CARRIER
U3: AMS1117-3.3; SOT-223-3_TabPin2
U5: 74HC595; DIP-16_W7.62mm
U6: MAX98357A

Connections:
+3.3V: C2.2, J4.1, J6.4, J7.8, U1.1 (3V3), U2.10 (VDD), U3.2 (VO), U5.10 (~SRCLR), U5.16 (VCC), U6.1 (VIN)
+12V: C1.1, J2.1, J7.9, U2.16 (VMOT), U3.3 (VI)
/BCLK: U1.10 (DAC_2/ADC2_CH9/GPIO26), U6.5 (BCLK)
/DIN: U1.37 (GPIO23), U6.4 (DIN)
/Dir: U1.31 (GPIO19), U2.8 (DIR)
/LRC: U1.9 (DAC_1/ADC2_CH8/GPIO25), U6.6 (LRC)
/Limit_In: J4.2, R1.1, U1.33 (GPIO21)
/Matrix_I1: J5.4, R5.2, U1.6 (VDET_2/GPIO35/ADC1_CH7)
/Matrix_I2: J5.3, R4.2, U1.5 (VDET_1/GPIO34/ADC1_CH6)
/Matrix_I3: J5.2, R2.2, U1.4 (SENSOR_VN/GPIO39/ADC1_CH3)
/Matrix_I4: J5.1, R3.2, U1.3 (SENSOR_VP/GPIO36/ADC1_CH0)
/Matrix_O1: J5.8, U1.24 (ADC2_CH2/*GPIO2)
/Matrix_O2: J5.5, U1.11 (ADC2_CH7/GPIO27)
/Matrix_O3: J5.6, U1.8 (32K_XN/GPIO33/ADC1_CH5)
/Matrix_O4: J5.7, U1.7 (32K_XP/GPIO32/ADC1_CH4)
/RCLK: U1.28 (GPIO17), U5.12 (RCLK)
/RX: J6.2, U1.34 (U0RXD/GPIO3)
/SER: U1.29 (*GPIO5), U5.14 (SER)
/SRCLK: U1.27 (GPIO16), U5.11 (SRCLK)
/Step: U1.30 (GPIO18), U2.7 (STEP)
/Stepper_Ena: U1.36 (GPIO22), U2.1 (~ENABLE)
/TX: J6.1, U1.35 (U0TXD/GPIO1)
GND: C1.2, C2.1, J2.2, J6.3, J7.10, R1.2, R2.1, R3.1, R4.1, R5.1, U1.32 (GND), U1.38 (GND), U2.9 (GND), U2.15 (GND), U3.1 (GND), U5.8 (GND), U5.13 (~OE), U6.2 (GND), U6.3 (GAIN)
unnamed: J1.1, U2.14 (2B)
unnamed: J1.2, U2.13 (2A)
unnamed: J1.3, U2.12 (1A)
unnamed: J1.4, U2.11 (1B)
unnamed: J7.1, U5.15 (QA)
unnamed: J7.2, U5.1 (QB)
unnamed: J7.3, U5.2 (QC)
unnamed: J7.4, U5.3 (QD)
unnamed: J7.5, U5.4 (QE)
unnamed: J7.6, U5.5 (QF)
unnamed: J7.7, U5.6 (QG)
unnamed: U2.5 (~RESET), U2.6 (~SLEEP)

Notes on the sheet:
No need capacitor in VI to GND because already in a4988
For production, probably needs its own power supply

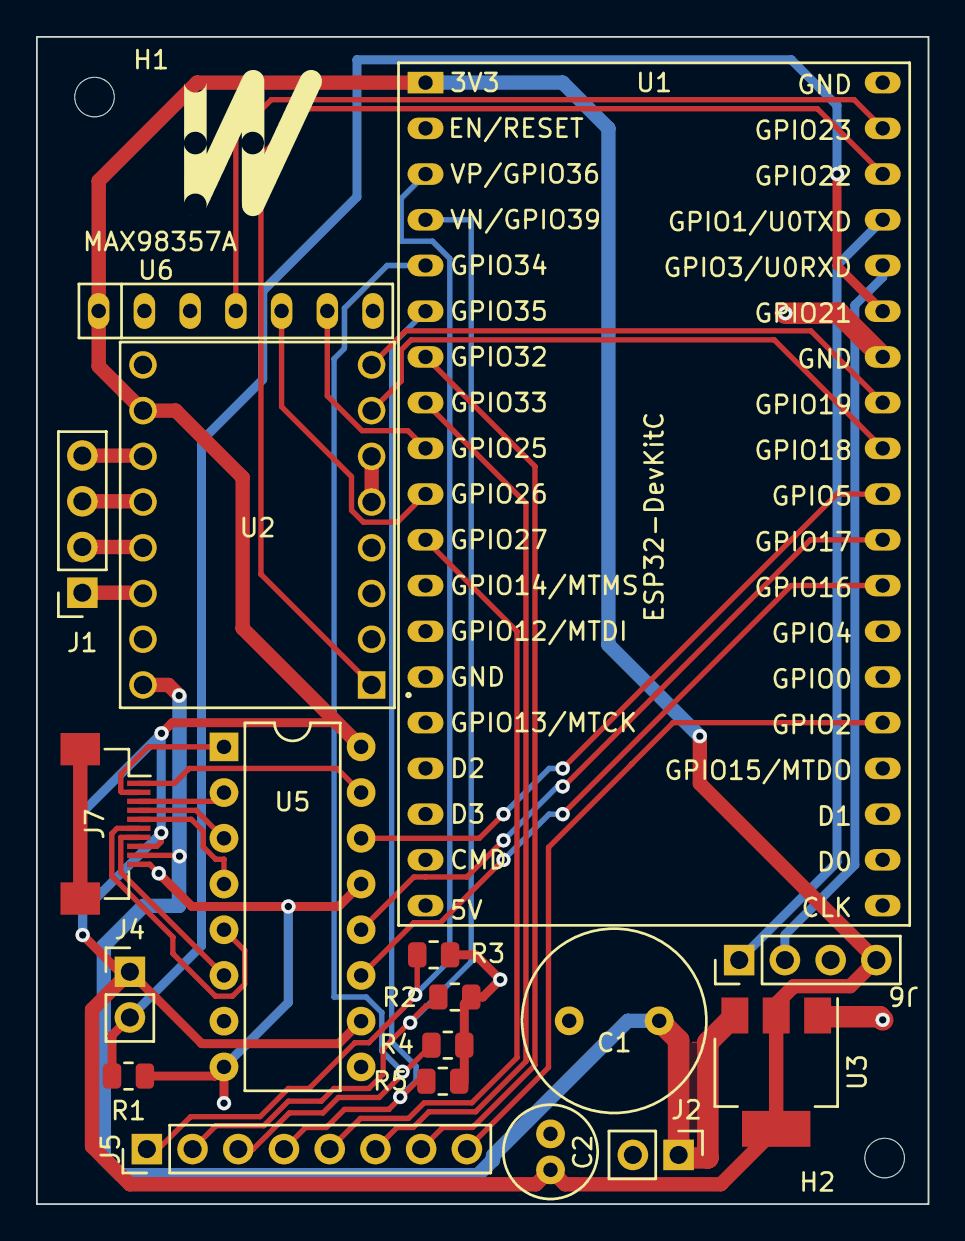
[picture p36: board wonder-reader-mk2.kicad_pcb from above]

Board: 2 copper layers, 49.5 x 64.8 mm, 20 parts (0 on the bottom side), 35 nets.

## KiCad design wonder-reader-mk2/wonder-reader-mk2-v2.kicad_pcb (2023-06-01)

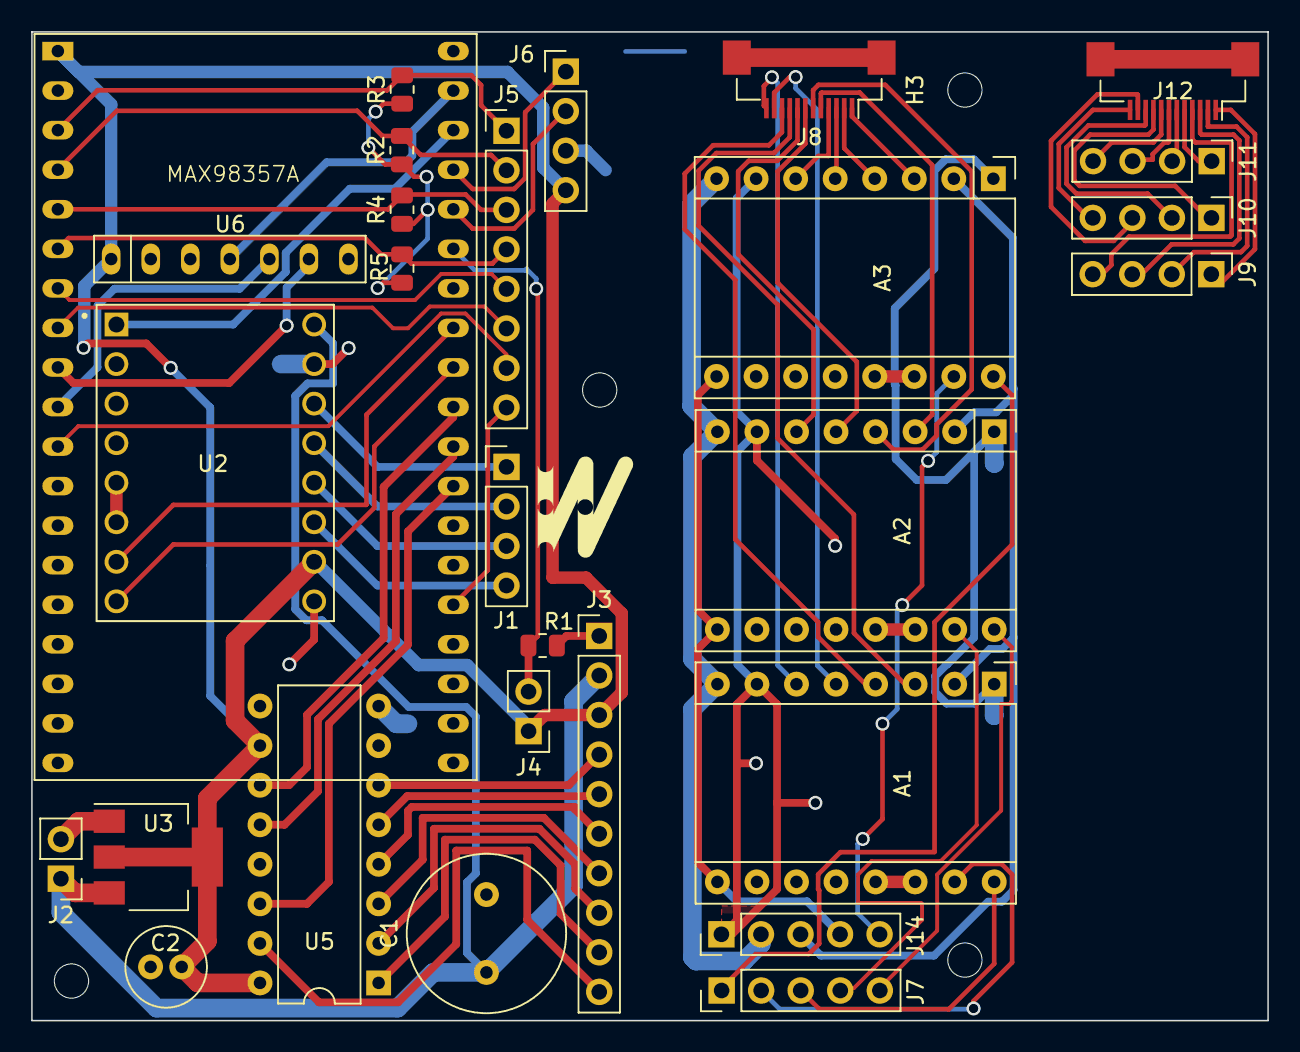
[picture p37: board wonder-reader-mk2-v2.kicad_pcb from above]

Board: 2 copper layers, 79.4 x 63.5 mm, 32 parts (0 on the bottom side), 71 nets.

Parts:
A1, A2, A3: Pololu_Breakout_A4988; Pololu_Breakout-16_15.2x20.3mm
C1: 1000u; C_Radial_D10.0mm_H16.0mm_P5.00mm
C2: 33u; C_Radial_D5.0mm_H11.0mm_P2.00mm
H1, H2, H3, H4: MountingHole; MountingHole_2.2mm_M2
J1, J6, J9, J10, J11: Conn_01x04_Pin; PinHeader_1x04_P2.54mm_Vertical
J2, J4: Conn_01x02_Pin; PinHeader_1x02_P2.54mm_Vertical
J3: Conn_01x10_Pin; PinHeader_1x10_P2.54mm_Vertical
J5: Conn_01x08_Pin; PinHeader_1x08_P2.54mm_Vertical
J7, J14: Conn_01x05_Pin; PinHeader_1x05_P2.54mm_Vertical
J8, J12: Conn_01x12_MountingPin; Hirose_FH12-12S-0.5SH_1x12-1MP_P0.50mm_Horizontal
R1, R2, R3, R4, R5: 10K; R_0805_2012Metric
U1: ESP32-DevKitC
U2: A4988_STEPPER_MOTOR_DRIVER_CARRIER; MODULE_A4988_STEPPER_MOTOR_DRIVER_CARRIER
U3: AMS1117-3.3; SOT-223-3_TabPin2
U5: 74HC595; DIP-16_W7.62mm
U6: MAX98357A

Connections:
+3.3V: C2.2, J3.3, J4.1, J6.4, U1.1 (3V3), U2.10 (VDD), U3.2 (VO), U5.10 (~SRCLR), U5.16 (VCC), U6.1 (VIN)
+12V: C1.1, J2.1, J3.2, U2.16 (VMOT), U3.3 (VI)
/BCLK: U1.10 (DAC_2/ADC2_CH9/GPIO26), U6.5 (BCLK)
/DIN: U1.37 (GPIO23), U6.4 (DIN)
/Dir: U1.30 (GPIO18), U2.8 (DIR)
/LRC: U1.9 (DAC_1/ADC2_CH8/GPIO25), U6.6 (LRC)
/Limit_In: J4.2, R1.1, U1.33 (GPIO21)
/Matrix_I1: J5.4, R5.2, U1.6 (VDET_2/GPIO35/ADC1_CH7)
/Matrix_I2: J5.3, R4.2, U1.5 (VDET_1/GPIO34/ADC1_CH6)
/Matrix_I3: J5.2, R2.2, U1.4 (SENSOR_VN/GPIO39/ADC1_CH3)
/Matrix_I4: J5.1, R3.2, U1.3 (SENSOR_VP/GPIO36/ADC1_CH0)
/Matrix_O1: J5.8, U1.24 (ADC2_CH2/*GPIO2)
/Matrix_O2: J5.7, U1.11 (ADC2_CH7/GPIO27)
/Matrix_O3: J5.6, U1.8 (32K_XN/GPIO33/ADC1_CH5)
/Matrix_O4: J5.5, U1.7 (32K_XP/GPIO32/ADC1_CH4)
/RCLK: U1.28 (GPIO17), U5.12 (RCLK)
/RX: J6.2, U1.34 (U0RXD/GPIO3)
/SER: U1.29 (*GPIO5), U5.11 (SRCLK)
/SRCLK: U1.27 (GPIO16), U5.14 (SER)
/Step: U1.31 (GPIO19), U2.7 (STEP)
/Stepper_Ena: U1.36 (GPIO22), U2.1 (~ENABLE)
/TX: J6.1, U1.35 (U0TXD/GPIO1)
GND: A1.1 (GND), A1.7 (GND), A2.1 (GND), A2.7 (GND), A3.1 (GND), A3.7 (GND), C1.2, C2.1, J2.2, J3.1, J6.3, J14.1, R1.2, R2.1, R3.1, R4.1, R5.1, U1.32 (GND), U1.38 (GND), U2.9 (GND), U2.15 (GND), U3.1 (GND), U5.8 (GND), U5.13 (~OE), U6.2 (GND), U6.3 (GAIN)
unnamed: A1.4 (1A), J8.10
unnamed: A1.3 (1B), J8.9
unnamed: A1.5 (2A), J8.11
unnamed: A1.6 (2B), J8.12
unnamed: A1.16 (DIR), J7.3
unnamed: A1.15 (STEP), J7.2
unnamed: A1.2 (VDD), A2.2 (VDD), A3.2 (VDD), J14.3
unnamed: A1.8 (VMOT), A2.8 (VMOT), A3.8 (VMOT), J14.2
unnamed: A1.9 (~ENABLE), A2.9 (~ENABLE), A3.9 (~ENABLE), J14.4
unnamed: A1.13 (~RESET), A1.14 (~SLEEP)
unnamed: A2.4 (1A), J8.6
unnamed: A2.3 (1B), J8.5
unnamed: A2.5 (2A), J8.7
unnamed: A2.6 (2B), J8.8
unnamed: A2.16 (DIR), J7.5
unnamed: A2.15 (STEP), J7.4
unnamed: A2.13 (~RESET), A2.14 (~SLEEP)
unnamed: A3.4 (1A), J8.2
unnamed: A3.3 (1B), J8.1
unnamed: A3.5 (2A), J8.3
unnamed: A3.6 (2B), J8.4
unnamed: A3.16 (DIR), J7.1
unnamed: A3.15 (STEP), J14.5
unnamed: A3.13 (~RESET), A3.14 (~SLEEP)
unnamed: J1.1, U2.14 (2B)
unnamed: J1.2, U2.13 (2A)
unnamed: J1.3, U2.12 (1A)
unnamed: J1.4, U2.11 (1B)
unnamed: J3.4, U5.6 (QG)
unnamed: J3.5, U5.5 (QF)
unnamed: J3.6, U5.4 (QE)
unnamed: J3.7, U5.3 (QD)
unnamed: J3.8, U5.2 (QC)
unnamed: J3.9, U5.1 (QB)
unnamed: J3.10, U5.15 (QA)
unnamed: J10.1, J12.9
unnamed: J10.2, J12.10
unnamed: J10.3, J12.11
unnamed: J10.4, J12.12
unnamed: J11.1, J12.5
unnamed: J11.2, J12.6
unnamed: J11.3, J12.7
unnamed: J11.4, J12.8
unnamed: J9.1, J12.1
unnamed: J9.2, J12.2
unnamed: J9.3, J12.3
unnamed: J9.4, J12.4
unnamed: U2.5 (~RESET), U2.6 (~SLEEP)

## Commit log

2023-01-26 First prototype
    [Wonder Reader Mk 0_1.stl]
2023-02-05 Added wonder reader mk1 files
    [Wonder Reader Mk 0_1.stl, Wonder Reader Mk 1 v68.stl]
2023-02-05 Initial design for mk2
    [cell_body.stl, cell_top.stl, pin1n4.stl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]
2023-02-10 Added some carriage components
    [bearing_bracket_end.stl, carriage.stl, carriage_load_L.stl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]
2023-02-15 Added updated cad models to hopefully final cell design. Added some renders
    [Wonder Reader Mk2.3mf, bearing_bracket_end.stl, bearing_bracket_start.stl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]
2023-02-20 Added kicad schematic design
    [cell_body.stl, grabber_gear.stl, grabber_rack_middle.stl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]
2023-02-28 Updated cell top height. Carriage load now can be joined together as they have a connecttor. New gearbox for x stepper motor speed. Updated PCB design
    [Wonder Reader Mk2.3mf, bearing_bracket_start.stl, carriage_load_L.stl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]
2023-03-06 New 1:3 gearbox. Bearing bracket start second gear holder not hitting screw
    [bearing_bracket_start.stl, gearbox_1.stl, gearbox_2.stl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]
2023-03-09 Added new model for new carriage
    [Wonder Reader Mk2.3mf, bearing_bracket_end.stl, bearing_bracket_start.stl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]
2023-04-02 Added cases and switches. Updated carriage load models and bearing brackets. Schematic update
    [Body40.stl, Wonder Reader Mk2.3mf, badge.stl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]
2023-05-15 Added new pcb and more step files for mark 2. Renamed previous mark 2 to mark 1 and mark 1 to mark 0
    [Body40.stl, Wonder Reader Mk 0_1.stl, Wonder Reader Mk 1 v68.stl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]
2023-06-01 PCB and new models for mark 2
    [arm.stl, badge.stl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]
2023-06-03 Updated arm and wedge model for more stability
    [arm.stl, arm_new.stl, holder-right.stl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]
2023-12-19 Added new Wonder Reader schematics
    [Body40.stl, Wonder Reader Mk 0_1.stl, Wonder Reader Mk 1 v68.stl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]
2024-01-09 Completed new wonder reader pcb
    [wonder_reader.kicad_pcb, wonder_reader.kicad_sch]
2024-01-10 Updated pcb to lower costs and rectify faults
    [wonder_reader.kicad_pcb, wonder_reader.kicad_sch]
